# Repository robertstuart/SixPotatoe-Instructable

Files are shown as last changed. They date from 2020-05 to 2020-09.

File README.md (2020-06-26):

# SixPotatoe-Instructable
This repository contains all of the code and documentation needed to construct SixPotatoe, a high-performance inverted-pendulum robot.   A complete tutorial for building this robot can be found at: https://www.instructables.com/id/Build-a-High-Performance-Inverted-Pendulum-Robot/.

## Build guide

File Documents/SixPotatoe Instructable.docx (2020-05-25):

# Build a High-Performance Inverted Pendulum Robot

YouTube

(https://youtu.be/zkr5eXEhqio)

## Supplies:

Most of the parts are a available and some can probably be found locally. The only components that have only one source are the motors from Servo City and the motor controllers from Pololu.

- Printed Circuit Board (PCB). This must be ordered from a manufacturer. Step 1 explains how to do this. For people with the necessary skills, it is entirely possible to build SixPotatoe using a breadboard or prototyping board.
- Motor Controllers (https://www.pololu.com/product/2995) from Pololu. I use the 24v13 controllers but any of the single channel High Power controllers in this category should work.
- 5V Regulator (https://www.pololu.com/product/3782) from Pololu.
- Planetary gear motors (https://www.servocity.com/motors-actuators/gear-motors/heavy-duty-gear-motors) from ServoCity. SixPotatoe is pre-configured to handle five of these motors. These motors are described at the end of this section.
- Encoder cables. If you are using the Yellow Jacket motors, you will need these cables (https://www.servocity.com/encoder-breakout-cable-4-pos-jst-xh-mh-fc-to-4-x-1-pos-tjc8-mh-fc-300mm-length) (2). The HD motors already have the cables attached
- 6mm Clamping D hubs (https://www.servocity.com/0-770-clamping-d-hubs) (2) from ServoCity.
- 6-32, 1/2" screws (8) to attach the clamping hubs to the base plate.
- 12mm Hex Wheel Mount (https://www.servocity.com/12mm-hex-wheel-mount-hub-2-pack) (2) from ServoCity.
- 32mm Bore Bottom Tapped Clamping Mount (https://www.servocity.com/32mm-bore-clamping-mount)(4) from ServoCity.
- LIPO battery. I use a Turnigy 1200 mAh battery (https://hobbyking.com/en_us/turnigy-graphene-panther-1200mah-6s-75c-battery-pack-w-xt60.html). The battery should have XT60 connectors. Almost any six cell batteries will work. This battery will run for more than an hour before needing to be recharged. Larger batteries give more operating time but also give more weight at the top which helps climbing steep slopes and over rough ground. However, small batteries can give the same performance improvement if mounted high enough.
- XT60 connectors (https://www.amazon.com/LingSY-Female-Bullet-Connectors-Battery/dp/B06XV8L8L8). You will need one male connector to mount on the PCB. You will probably need a male and female connector to make a small battery cable if your battery does not have a long enough cable.
- 16 ga. black and red battery wire. Almost any stranded 14-18 ga. wire will work although I have a strong preference for silicon wire which is available from Hobby King (https://hobbyking.com/en_us/turnigy-high-quality-16awg-silicone-wire-1m-black.html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) or Amazon (https://www.amazon.com/Electrical-Gauge-Silicone-Cable-Black/dp/B0746HRVZP).
- Teensy 4.0 Arduino controller. These are available from a variety of sources including Sparkfun (https://www.sparkfun.com/products/15583)and PJRC (https://www.pjrc.com/store/teensy40_pins.html).
- Electrolytic capacitors for the motor controllers (2). I use 330uf from Pololu (https://www.pololu.com/product/882). Pololu recommend larger capacitors. A higher voltage would also be a good idea.
- 6 channel RC receiver and transmitter (https://www.amazon.com/DUMBORC-X6-Transmitter-Receiver-Protections-Controller/dp/B07Q112TQF). This is an inexpensive but very capable controller. This Instructable is designed around this controller although other controllers would probably work with a little modification.
- IMU (https://www.sparkfun.com/products/15335) from Sparkfun. This is an ICM-20948 mounted on a breakout with a Qwiic connector. The Qwiic connector can be used to add other sensors at a later point.
- HDPE sheets (https://www.amazon.com/Density-Polyethylene-Plastic-Sheet-Black/dp/B01JMAIYJW/). Other material can probably be used such as Phenolic sheets (https://www.amazon.com/Phenolic-Sheet-Standard-Tolerance-MIL-I-24768/dp/B0013HKZG8?th=1), alumunum or even baltic birch plywood. However, the frame needs to be very stiff, especially the base plate! I normally use 1/4" thick HDPE for all the plastic parts although I often use 3/8" for the bumpers. For the bumpers, HPDE is probably the only suitable material because of its extreme durability. I buy my HPDE from the scrap bin of a local plastics fabricator, but it is widely available from other sources.
- Threaded rod to hold the platforms. I use M5 rods from Amazon (https://www.amazon.com/uxcell-130mm-Stainless-Threaded-Silver/dp/B01M665GED?s=hi) but other sizes work just as well including 6mm, 10-32, 12-24, and 1/4". You will need four lengths that will normally end up with a length of 120 to 160mm. The ones listed from Amazon are 130mm which quite suitable.
- Wheels & Tires. I use Pro-Line F/R Masher 2.8" A/T Tires (https://www.prolineracing.com/tires/masher-2.8-all-terrain-tires-mounted-raid.asp), but many other tires will work just fine. The wheel must have 12mm hex mounts, which is standard for 1/10 scale vehicles. Also, the wheel should have a "wide offset". Any wheel that fits a 2wd Stampede®/Rustler® Front or 4x4 Stampede®/Rustler® Front and Rear should work. Even wheels with a narrow offset can be made to work by cutting away a bit of the base plate for tire clearance. The softer (more grippy) the rubber, the better. Also, the bigger the tire with more cushioning, the better. On the other hand, if you just plan on running on flat surfaces --- even grassy areas --- wheels like those from Bainbot (http://www.banebots.com/category/T81P_49.html) work nicely.
- LED momentary contact switch. The PCB is designed to use this switch from Sparkfun (https://www.sparkfun.com/products/10443). You may find it more convenient to mount a switch on the top plate. There are connection points on the PCB that makes it easy to hook up a cable to do this. For this, I like the LED switches from Adafruit (https://www.adafruit.com/product/1479).
- Hardware for mounting the PCBs. There are a number of ways to do this and all of them work just fine. You should choose hardware based on what currently have or what is available locally. Read the description in Step 8: Mounting the PCBs to understand the options.
- Mounting hardware for the PCBs. You should read the instructions in Step 8: Mounting the PCBs before deciding what parts to use.
- Male Header (https://www.sparkfun.com/products/116)
- Female headers (https://www.sparkfun.com/products/115) (2).
- Schottky Diode (https://www.sparkfun.com/products/10926) (2).
- Ceramic Capacitor 0.1uF (https://www.sparkfun.com/products/8375)
- Electrolytic Capacitor 100uF (https://www.sparkfun.com/products/96)
- Qwiic cable (https://www.sparkfun.com/products/14426).
- Seven resistors: One each of 150 ohm, 470k ohm and 68k ohm and four 1k ohm resistors.

If you can't find some of the miscellaneous electronic components locally or in your parts bin, they can be purchased from either Digikey.com or Mouser.com. Many of the small mechanical parts can be purchased at your local hardware store. If they don't have exactly the part specified, you can usually find something similar there that will work just fine.

The total price for these components should be $400 - $500.

Before starting this project, you will probably want download and print out the mechanical drawings in the repository. These can be found in https://github.com/robertstuart/SixPotatoe-Instructable, in the “Mechanical Drawings” directory.

## Tools

- Table or band saw to cut the platforms.
- Drill. A drill press is nice but not absolutely necessary.
- Saw to cut the bumpers. The bumpers could be omitted but this is not recommended. A jig saw, coping saw or even a router could be used to fashion the bumpers. I expect that those with good 3D printer skills could make something that would work quite well.
- Soldering iron. A temperature controlled iron is recommended.
- A modest assortment of screwdrivers, wrenches, and pliers

## Choosing a motor

The robot can use any of the following motors, available from Servo City. I have tried all of these motors and I have a slight preference for the HD 612 RPM but there are reasons, including availability, that you might want to choose another one. Here is the complete list:

Yellow Jacket 435 RPM - This motor is a little cheaper, is a little less powerful that the equivalent HD motor listed next. The encoders don't have as much precision. Still, the differences would be hard to detect in most situations. Its top safe speed is around 15 KPH (9 MPH).

HD 437 RPM - For all practical purposes, this motor is equivalent to the Yellow Jacket 435 motor described above. It does have a teeny bit more power and better encoder precision, so in rare instances it will perform a little better. In fact, SixPotatoe used this motor in all of the skate park “dimple” scenes in the YouTube videos.

HD 612 RPM - This is the ideal motor for many people. In fact, I delayed the publication of this Instructable until this motor became available again. Its top speed is around 21 KPH (14 MPH) and it manages jumps and rough ground with ease and is plenty fast. It is very stable and runs a long time on one battery charge.

Yellow Jacket 1150 RPM - This motor is just like the Yellow Jacket 435 RPM motor but is almost three times as fast. It won't stay upright quite as well over rough ground and jumps, but the speed is very impressive. It is a lot of fun to drive. Its top safe speed is around 40 KPH (25 MPH). In my opinion, this is really faster than you will normally want to go. It can do considerable damage to itself, other things and people when it hits something at that speed. It will appear to be slightly unstable and out-of-control at its top speeds since it will bounce a little bit when encountering slight undulations in the surface. It consumes considerable battery power; especially over rough terrain and the motors will get slightly warm. SixPotatoe was using this motor for most of the high-speed scenes in the YouTube video.

HD 1621 RPM - If you are addicted to speed and your personal and property insurance payments are up to date, this is the motor for you. Its top speed is about 55 kph (36 mph). In the skate park, I have made some really spectacular jumps using this motor. (I have been unsuccessful in making it land properly in many cases, so there is often damage. As a result, I have abandoned any further attempts.) Its operation over rough ground is not up to that of the lower RPM motors, but it is still very impressive. The safety, battery power and motor temperature caveats of the previous motor apply even more to this motor. Also, I have not done as much testing with this motor so it may not be as well tuned as it could be.

## Step 1: Create the PCB

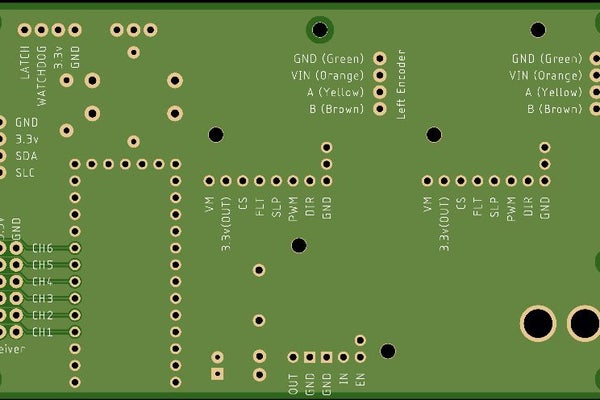
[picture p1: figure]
Create the PCB
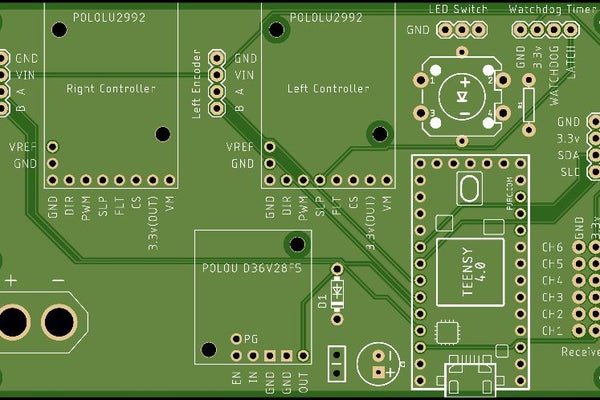
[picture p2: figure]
Create the PCB

The Gerber file for manufacturing the PCB is included in the Eagle Files directory of the GitHub Repository (https://github.com/robertstuart/SixPotatoe-Instructable). There are a variety of PCB manufacturers but we have been very happy with the price, quality, and delivery times of JLCPCB (https://jlcpcb.com/). Whatever manufacturer you use, follow the directions from the manufacturer for uploading the Gerber file and ordering your board(s).

Note that it is possible to make this robot using prototyping boards or even breadboards. In fact, early versions of this robot were made using both of these methods. The schematic should give you all of the information you need. The wiring diagram, Wiring.pdf, also available from the GitHub Repository, should also help but be aware that it is doesn't exactly reflect the schematic. Use the schematic and just use the wiring diagram as a general guide!

## Step 2: Top and Bottom Plates

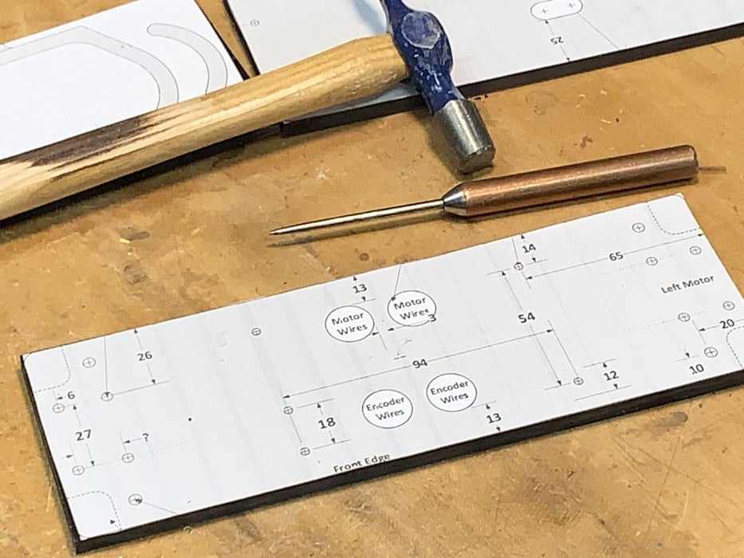
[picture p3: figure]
Top and Bottom Plates
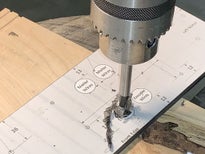
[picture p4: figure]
Top and Bottom Plates
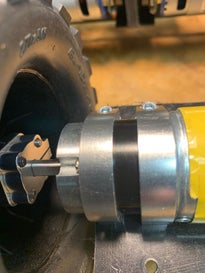
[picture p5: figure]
Top and Bottom Plates
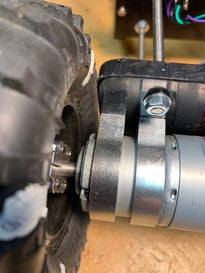
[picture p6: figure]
Top and Bottom Plates

Cut the two HDPE plates to the dimensions shown in the mechanical drawing. Ideally, this can be done on a table saw but a band saw works also. It is a good idea to round the four corners an all the edges. This can be done with a sander. A wood plane also works quite well. The edges can also be carved smooth with a regular knife or an Exacto knife.

To drill the holes it is usually easiest to make a template by printing out the mechanical drawing. Be sure to print them out using a scale of 100%! Then tape or glue the drawing to the platform. Gluing with rubber cement usually works best. You can then punch the center of each hole with an awl or center punch to give a solid target for the drill so that the bit doesn't wander. The holes can be done with a hand drill although a drill press is a little easier. I find that a forstner bit works best for the larger holes.

Only the motor mounts require any accuracy. To get the spacing between the two motor mounts, install the clamps on your motors and measure the spacing. Normally, you will want to have the gear box protrude a bit from the outside motor mount. I usually adjust the position so that the heads of the screws holding the gearbox end cap are just outside the clamp. The picture shows this relationship.

On the top plate, do not drill the holes for the bumpers. These can be more accurately drilled when the bumpers are completed in the next step.

## Step 3: Bumpers

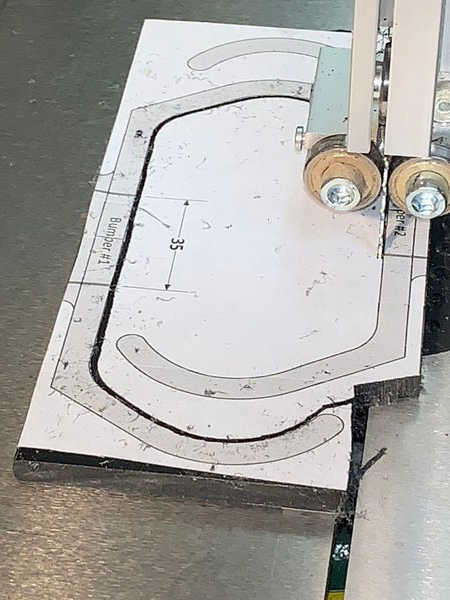
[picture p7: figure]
Bumpers
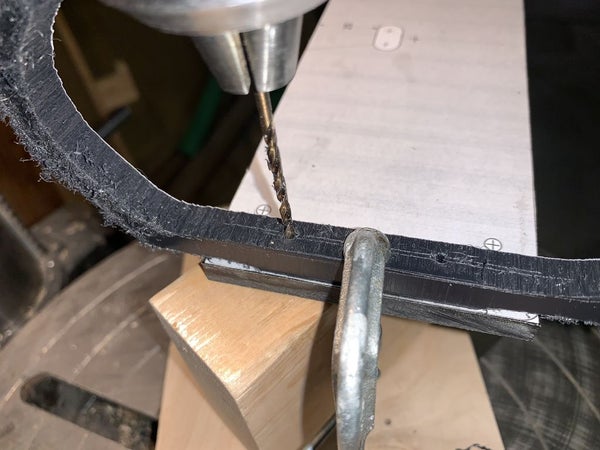
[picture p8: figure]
Bumpers

Again, the easiest way to create the bumpers is to use the printed diagram as a template. There are two base lines that indicate the bottoms of the bumpers where they will be attached to the top plate. Measure the distance between these two lines. Cut out a plate off HDPE so that it has exactly this width. Cut out the printout along these base lines and then glue the template to the plastic, aligning the baselines with the edges. The bumpers can be cut out on a band saw. A simple coping saw also works quite well. After cutting, the edges can be smoothed by carving with a knife or sanding using a medium grade sandpaper.

1/4" HDPE works well for the bumpers but I have a slight preference for 3/8" HDPE since it is a little stronger. The bumpers are the most likely part to get damaged in a driving accident, so you might consider making a couple more at this point. If you are a careful driver, you can just make the required two.

Once the bumpers are cut, you should drill the two mounting holes. This is something you should do very carefully. The bumpers are most likely to break at these mounting holes. They will be strongest if you drill exactly in the center. This hole should be quite small. I normally use M2.5 or 4/40 screws. The holes for the screws should be slightly smaller than the screw. This way you will be able to drive the screw through the hole with a hammer so that the sides of the plastic will bulge out slightly.

After you drill the holes but before you drive in the screws, you should clamp the bumpers to the top plate in their correct position. Using the same drill bit, you can use the bumpers as a drill guide to drill through the top plate. When you un-clamp the pieces, you can then re-drill the hole through the plate so that it has better clearance. When you finally mount the clamp on the top plate, it is a good idea to put a washer underneath the head of the screw. Also, since it is normal to carry SixPotatoe using these bumpers as a handle, it is a good idea to grind off any part of the screw that protrudes from the nut it so that it is comfortable to carry in this manner.

## Step 4: Encoder Shields

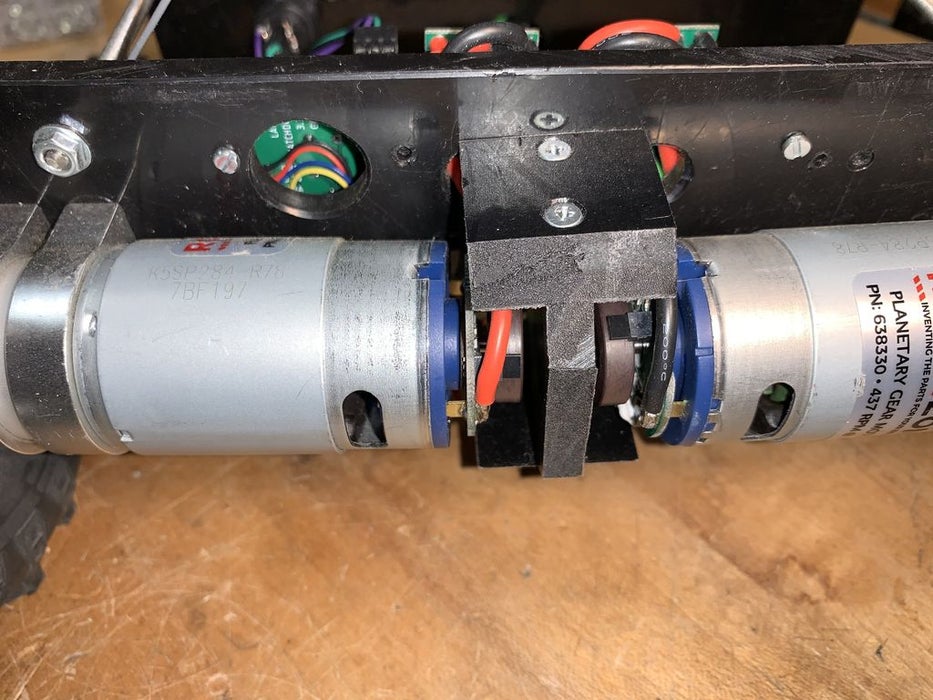
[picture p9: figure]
Encoder Shields

The encoder shields protect the encoders from damage, which can easily happen over rocky ground. They also add stiffness to the entire base plate.

First of all, you have to decide what kind of screws to use to hold these pieces together. Smallish flat head self tapping (sheet metal) screws work best. M3, 20mm are about the right size. In the USA, #4 or #f6 sheet metal screws of about 3/4" in length work well. You may want to use the same size and type of screw in the battery tower in the next step.

Cut out the two sides as shown in mechanical drawing. The shape is not important. Place one of the sides in its proper position and, using an awl, mark the position of the holes on the center piece. This gives the vertical position of the screw. Hold the center piece in a vice or clamp and carefully mark the position of the screw hole in the center of the piece using the previously marked position to get the height. Then drill a guide hole the depth of the screw. Countersink the hole for the flathead screws. Attach the 3 pieces with the screws.

Find the proper placement for the shield. This should be in the exact center, both vertically and horizontally. You may want to temporarily mount the motors to make sure that the position is correct. Mark the position of the shield on the bottom of the bottom plate. Masking tape is probably the best way to do this since no pen or pencil can mark on this plastic. Alternatively, an awl can be used to scratch the outline. You then need to drill four holes in the assembly to accommodate the self taping screws. The size of the drill should be about the size of the shaft of the self taping screw so that the screws get a good grip. Once the hole are drilled in the shield, you can then punch centering holes in the base plate to match the shield assembly. Then drill the matching holes through the base plate with a drill bit that creates clearance for the self taping screws. Once that is done, you can mount the shield with the screws.

This technique for mounting the shield will also be used in the next stop to create the battery tower.

## Step 5: Battery Tower

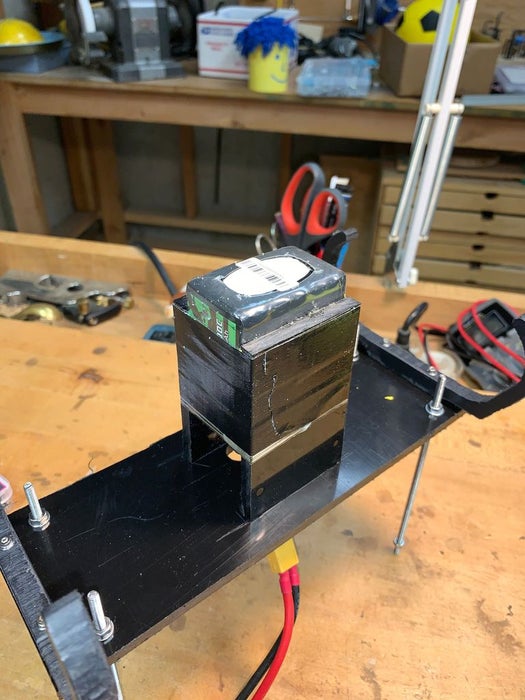
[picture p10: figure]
Battery Tower
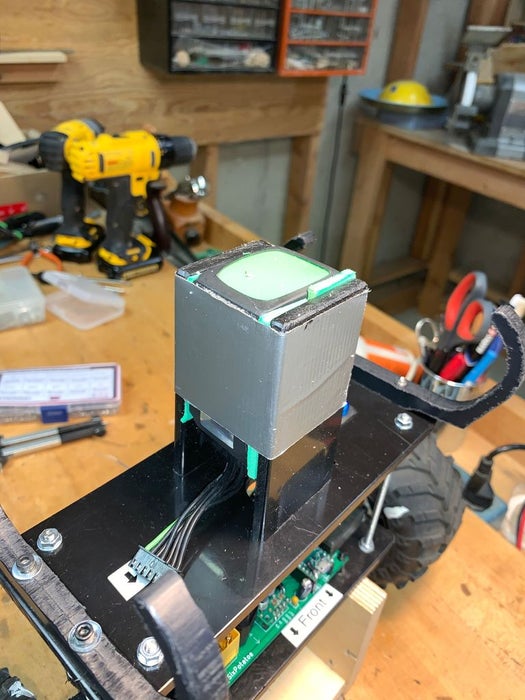
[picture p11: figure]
Battery Tower

The battery tower is not absolutely required. In fact, all batteries, especially larger batteries, can just be strapped to the top plate so that the battery tower is not needed at all. The battery tower, described here, helps a little bit with performance on steep slopes and rough ground, so it is the preferred method. If you decide to mount the battery flat on the top plate, you might consider lengthening the threaded rods to regain this lost performance. Another consideration is that the battery tower makes it easier to mount a head on the robot.

The battery tower must be custom fit to battery that you have. If the power wires on the battery are long enough, you may be able to plug directly into the PCB. For many batteries, however, you will have to manufacture a short extension so that the battery can be mounted at the proper height. For the specified battery, a height of around 90 mm seems about right. The width should be as wide as the battery.

Once the size is determined and the pieces are cut out, you may have to create some spacers to go between the battery and spacers. You can see this in one of the pictures above. This is because batteries are often a little wider at the end with the connectors. The spacers prevent any pressure on the connector wiring. Almost any material will work for spacers. Often cardboard is the easiest option.

Sandwich the tower pieces, spacers and battery together placing glue between each of the pieces. Rubber cement or contact cement works best in this situation. Double-sided sticky tape works well also. Lightly clamp the entire sandwich together and set it upright and adjust everything so that the bottoms rest flat on a horizontal surface and the sides are vertical. Allow the glue to dry. After the glue is reasonably dry, remove the clamps and tape the whole thing together. I like duct tape or electrical tape but almost any tape will work.

You must decide what kind of screw you are going to use to attach the tower to the top plate. M3 or M4 self taping screws of 20-30mm work well. In the US, #6 sheet metal screws of about 1" seem about right.

Take the battery tower and position it on the top plate so that it is properly centered. Mark the position of the battery tower supports on the top plate using masking tape. Turn the battery tower upside down and mark the position of the guide holes with an awl. These should be exactly centered on the supports and about 8mm from the end. As with the encoder shields, you need to drill tap holes into the tower sides and, after marking the position on the top plate, drill clearance holes in the top plate.

If you decide to mount and LED switch on the top plate, this is the time to do that.

Mount the battery tower guiding the power cable through the top plate.

Step 6: Mount the Motors

The motors should be bolted to the base plate using the .. There are slightly different directions for the HD and Yellow Jacket motors.

Yellow Jacket Motors:

Remove and throw away the plastic shields for the encoders. Wires from the motors need to be kept away from the encoder wires so that spikes from the motor do not interfere with the encoder signals. This interference can cause serious problems in the operation of the robot, particularly during aggressive maneuvers. Completely pull apart the red and black part of the wire pair. Mount the motors so that

HD Motors:

You should clip off the connector at the end of the six-wire cable. Then you should remove the red and black wires by clipping them off right at the encoder PCB. Cut two lengths of the red 16 Ga. stranded wire to about 130mm. Do the same for two pieces of the black wire. Strip off enough insulation from one end of each of the wires so that it can be soldered to the motor. Sold a red wire to the +M connection and a black wire to the -M connection. Be sure to solder them so that they are leading away from the encoder wires.

## Step 7: Prepare the Teensy

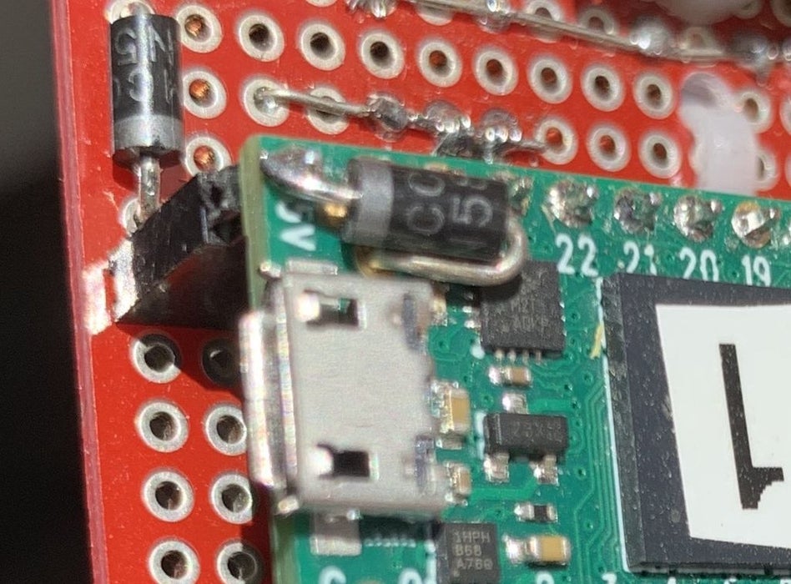
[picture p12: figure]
Prepare the Teensy

The Teensy 4.0 must be modified so that it can be powered by either the USB or the battery. A trace is cut on the back side of the board and a Schottky diode is added to the front side. The trace is shown on the "Teensy 4.0 Back Side" drawing here: https://www.pjrc.com/store/teensy40.html. On the diagram you can see a connection point labeled VUSB, This is the point where the anode side (without the stripe) of the diode must be connected on the top side. After cutting the trace on the back side, place the diode and solder it on the top side so that it connects the VUSB to the 5V (Vin) point as shown in the picture above.

If you have purchased your Teensy without headers, you must solder 14-pin male headers to the bottom side of the board.

## Step 8: Wire the Battery Connector on the PCB

By now, your PCBs should have arrived from China.

We will hook up the power connector first since that is easiest and safest to do when there are no other connectors of components on the board. It is best to have one or two people help you with this step since the PCB, the connector, and the wire all need to be held in place when soldering. First of all, cut two pieces of black and two pieces of red 16 guage wire to a length of about ??cm. Strip about 5mm of insulation from one end of each wire. I also like to insert a female connector (not from a battery!) into the male connector to make it easier to hold on to the connector.

Start heating your soldering iron. A good hot iron is needed. I set the temperature to about 400 degrees Celsius.

Now comes the hard part. I like to clamp the connector in a vice and then place the board onto the clamped connector. This is where you will need someone to hold the board onto the connector. This helper should use something like a screw driver or an awl to hold the board firmly onto the connector. Then place the two stripped ends of black wires into the negative terminal. and press the wires against the PCB while directing the wires toward where they will eventually connect to the motor controllers. Either have someone else hold the wires against the PCB or use something like a clothes pin to hold the wires.

Stop! Recheck to make sure that: 1) you are mounting the connector on the correct side of the board, 2) the connector + and - are oriented in the correct direction and 3) the black wires are connected to the minus side of connector terminal.

Now you can solder the wires. It will take some time to heat this all up, but once it is hot enough, the solder should flow easily. Apply just enough solder to just fill the connector. Be sure that the solder flows between the connector and the plated through hole on the PCB.

Solder the two red wires in the same manner.

Cut the headers so that you have two 14-pin strips to mount the Teensy and three 6-pin strips to mount the radio receiver. You should cut the strips at a pin, destroying that pin, so that you have the desired number of pins remaining. For the Teensy headers, the ends can be left rough if you want but the three 6-pin strips must be filed off so that they fit into the radio receiver housing. You can do this with a piece of medium sandpaper on a flat surface or with a file. Finger nail files work quite well for this. If you want to put a connector to an LED switch on the top plate, you can also create a 3-pin header for this.

Solder all of the headers to the PCB. This is another situation where it is helpful to have another person hold everything together while doing the soldering.

Solder the resistors, capacitors, and diode to the PCB. The resistors...

## Step 9: Mounting the PCBs

Before you mount the motor controllers, you should add the large electrolytic capacitors to them in the space provided. Be sure to get the polarity correct.

There are four circuit boards that are mounted directly on the main PCB: the two motor control boards, the 5V regulator and the IMU. The usual way to mount these is to use a standoff or spacer to hold the board away from the main PCB and then clamp the sandwich together using a screw and nut. A 6mm or 1/4" spacer works quite well. An M2 or 2-56 screw and nut holds them together. There are probably many other ways to do this. I find that the parts from this kit from Amazon (https://www.amazon.com/HVAZI-240pcs-Standoffs-Assortment-Male-Female/dp/B07JYSFMRY) contains almost everything you need except for the small screws. The IMU, mounted on the bottom, has larger mounting holes so you can use the M2.5 standoffs. In any case, a trip to the hardware store will usually yield a solution.

Once you have mounted all four boards, you need to use the same general technique to mount the main PCB to the bottom plate. I find that 10-15mm or 1/2" spacers are about right. The spacers should be long enough that IMU does not touch the base plate. The screws and nuts can be M2.5 or 4-40. Again, the spacer/standoff kit from Amazon has parts that work very well in this situation.

Mount all of the boards into their proper position. Note that the IMU is mounted with the connectors near the main PCB and oriented so that the label "ICM-20948" is nearest the Teensy.

Once the boards are mounted, the connections/jumpers can be installed. To do this, run a small solid wire between the board and the main PCB and the solder each end and clip off the ends. For the motor controllers, only the GND, DIR, and PWM need to be connected. For the regulator, only the IN, GND, GND, and OUT need to be connected.

The easiest way to connect the IMU is to hook up a QWIIC connector to the board and solder the wires from the connector to the GND, 3.3V. SDA, and SCL on the main PCB. If you have purchased a connector cable, you can snip off one of the connectors. The black wire will be GND, the red wire 3.3V, the blue wire SDA and the yellow will be SCL. You can also create your own connections using the plated through holes on the side of the IMU board. Note that the QWIIC connectors provide a convenient way to expand the capabilities of SixPotatoe without additional wiring.

The last step is to connect the wires from the battery connector to the motor controllers. Train the red and black wires to the GND and VIN connections on the controllers. Cut the wires to the proper length. Before stripping the wires, it is usually easiest if you tin the ends so that the wire doesn't fray when you strip the wire. After you strip the wire, place the red wire into the VIN and the black into the GND and solder them. It will take a fairly hot iron to do this but be careful; the board should not become so hot that other components on the board become unsoldered, thereby ruining the board. Pololu provides screw terminals that can be mounted on the boards. If you wish, you can use these rather than solder the wires.

## Step 10: Set Up the Arduino Development Environment

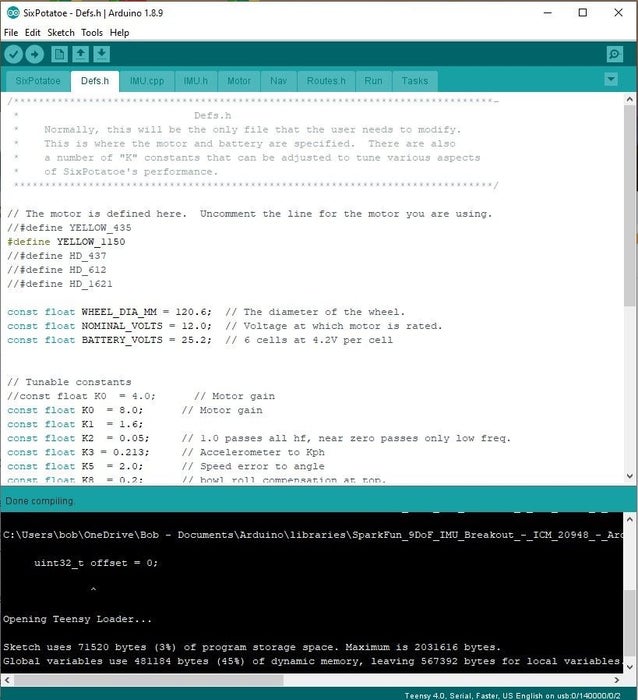
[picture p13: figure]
Set Up the Arduino Development Environment

If you have not used the Arduino development environment before, you need to spend a little time setting it up and learning how to use it. There are many tutorials (and Instructables!) that will get you going.

First of all, get the current SixPotatoe code from the GitHub repository, https://github.com/robertstuart/SixPotatoe-Instructable, and install it on your system. Again, if you have not used GitHub, there are tutorials and Instructables that explain how to do this. I think the easiest way is to click the "Clone or download" button and then download the zip file and put the code wherever you do your development.

You must then set up the Teensyduino environment. Go to this web page, https://www.pjrc.com/teensy/td_download.html, and follow the directions for your environment. Once everything is set up, you will have to start up the Arduino development environment, click on the "Tools" menu and select "Teensy4.0" from the "Board:" menu. Once you are this far, it is a good idea to hook up your Teensy to determine that the SixPotatoe compiles correctly.

## Step 11: System Testing

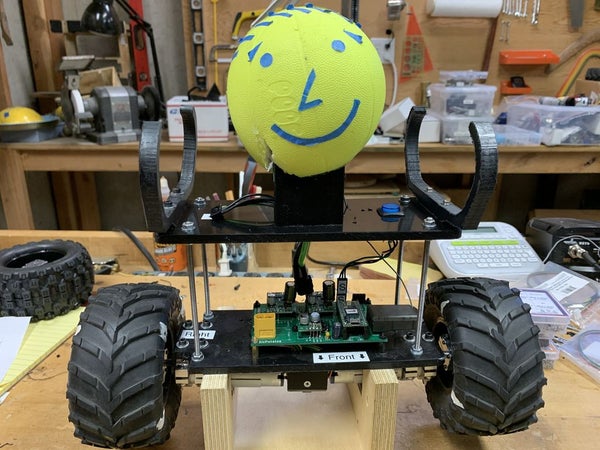
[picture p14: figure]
System Testing
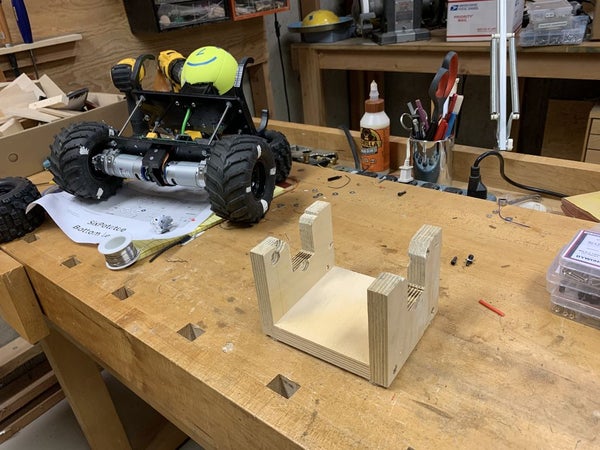
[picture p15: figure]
System Testing

Before you start testing and running SixPotate it is useful to have some sort of test stand. Something like four soda cans will work just fine but I like to make a simple stand out of wood. You can see the cradle that I use in the above pictures. Keeping SixPotatoe in the stand, also keeps the tires from developing "flat spots" when sitting around idle.

After all of the connections have been made, it is a good idea to make some simple checks to be sure that there are no major wiring errors. If you have an ohm meter, measure the resistance between the two battery terminals on the PCB. This should measure in the meg-ohms. You should do the same between the Gnd and Vin on the Teensy. These are the two end pins near the USB connector. This should also be in the meg -ohms.

Next, you must set values in your SixPotatoe.ino file to match the motors that you have installed. There are parameters for several motors already established in the file:

RZONE_1621
RZONE_612
RZONE_437
YELLOW_1140
YELLOW_435

One of these values must be specified in first #define in the beginning of the defs.ino file. The line defining your motor should be uncommented. This will establish appropriate values for each of these motors. If you have other motors, you can probably come up with reasonable values for your motors using the previous definitions as a guide.

There are four system tests:

System Test #1

This test checks that the IMU is working. Near the bottom of the defs.h file there are some lines that activate the system tests. You will need to set the appropriate system test to "true". For this test, you will need to set the lines as follows:

// Test defines

const bool IS_TEST1 = true; // Set to be true for the 1st system test.

const bool IS_TEST2 = false; // Set to be true for the 2nd system test.

const bool IS_TEST3 = false; // Set to be true for the 3nd system test.

const bool IS_TEST4 = false; // Set to be true for the 4th system test.

Hook up the USB connector on the Teensy to your computer that is running the Arduino development environment. The light in the RC receive should come on. Upload the SixPotatoe sketch and run the serial monitor. The LED on the Teensy should blink and the output on the serial monitor should show the pitch, roll, and yaw, in degrees, of SixPotatoe. Move SixPotatoe around and see if the orientation looks correct. All three values should be near zero when SixPotatoe is upright. The pitch should go positive as SixPotatoe is leaned back and negative as SixPotatoe is leaned forward. Roll will go positive as the left motor is lifted up and Yaw will go positive as SixPotatoe is rotated clockwise.

System Test #2

This test checks that the Radio Control works. If you haven't already done it, this is the time to bind the transmitter and receiver. Follow the instructions that came with the RC unit to do the binding.

Once the binding is complete set IS_TEST1 to false, and IS_TEST2 to true. Upload the program and look at the serial monitor output. Channel 1 value should vary as you turn the steering control, and channel 2 should vary as you manipulate the trigger (throttle). The top left control should change channel 5 and the top right control should change channel 6. Channel 3 is toggled by the push button on the side of the handle and Channel 4 has a 0, 1, and 2 state controlled by the slide switch.

System Test #3

This test checks the operation of the motor controllers and motor encoders. Also, SixPotatoe should be sitting up on a test stand of some sort. Plug the battery into the connector on the PCB. Unplug the USB from the computer. The LED on the Teensy should continue to blink. Plug the USB connector back in. Set IS_TEST3 to true and all of the other tests to false. Upload the new SixPotatoe program.

Press the LED push-button. The LED should come on. Toggle the on/off button on the controller. The LED on the switch should turn on and off just like the LED on the controller. Turn the LEDs on. Pull the trigger. Both motors should be operated both forward and backwards by the trigger. The motors should go forward when the trigger is pulled in and backwards with the trigger is pushed out.

The first two columns displayed in the serial output show the right and left wheel speed. The wheel speed should be positive when the trigger is pulled and negative when it is pushed out. The direction will vary depending on the motor encoders and gear box. If the direction is incorrect, this can be easily fixed by simply changing the pin definitions in SixPotatoe.ino.

Configuration A:

const int ENC_B_LEFT_PIN = 20;

const int ENC_A_LEFT_PIN = 21;

>const int ENC_B_RIGHT_PIN = 22;

const int ENC_A_RIGHT_PIN = 23;

Configuration B:

const int ENC_B_LEFT_PIN = 21;

const int ENC_A_LEFT_PIN = 20;

const int ENC_B_RIGHT_PIN = 23;

const int ENC_A_RIGHT_PIN = 22;

Use whichever configuration works for the motors you have.

The wheels will turn in opposite directions when the steering control is is manipulated.

This is probably the appropriate place to do the initial setup for the adjusting knobs that are underneath the lid on the controller. The bottom left knob adjusts the gain for the steering. This should probably be turned all the way up to 100. The knob above that sets the centering for the steering. This should be set at the center, 0. The right bottom knob sets the gain on the throttle. If you want to run the robot at maximum speed you must set this at 100. However, I recommend that this be set at 50 or lower while you are learning to operate the robot. Also, it is useful to set this at a low value for new users, particularly young children. The knob above that should be set to the center position.. It can be used to set the robot to zero speed. It can be quite useful to stand still on sloping ground.

Both of the switches at the top should be set to the left.

System Test #4

This test checks the internal control circuitry and software for motor speed control. As before, set IS_TEST4 to be true and all other tests to false. The motors can be turned on and off, either by pressing the button on SixPotatoe or CH3 on the controller. Again the measured speed will appear in the serial output. If SixPotatoe passes this test, it should work correctly in normal operation.

Preliminary balancing test

Set all the tests to false so that the system is in its normal running mode. Plug in the battery connector and the LED on the Teensy should show its heartbeat. While holding SixPotatoe nearly vertical, press the on/off button once and the LED on the button should come on. Press it again after a second or so, and the light should go off. The motor may have started up while the light was on. If you repeat this while tipping SixPotatoe forward or backwards a few degrees you will see that the motors will start accelerating more forward the more SixPotatoe is leaning forward. You will see the opposite effect as you tip SixPotatoe backwards. If this is what you see, your robot is ready to run!

## Step 12: Running SixPotatoe

I think that you will find that SixPotatoe is a lot of fun to drive. If you are not used to the RC controller, it takes a little time to get used to the steering and accelerator – particularly if you are using one of the high RPM motors. Here is some general information to help you get going:

Mounting the wheels

Mount the ”D” clamp on the end of the motor shaft. Make sure that the shaft does not protrude past the face of the clamp. Tighten the clamp. Then mount each of the 12mm wheel adapters to the clamp and tighten the four 6-32 screws.

Next, the wheels must be mounted on the wheel adapters. Be careful that the 8-32 wheel-mounting screw does not bottom out on the motor shaft. In the worst case, you can tell that the screw is bottomed out when the wheel is loose after tightening the screw. If the wheel feels solid, it is still sometimes safest to add another washer under the 8-32 screw to be sure that everything is tight.

The LEDs

When you connect the battery, the LED on the Teensy will start blinking at about two times a second. This tells you that it is going through its usual 200 per second cycle. If the light is not blinking, something is very wrong and SixPotatoe will not work.

The system LED on the switch should initially be off. If you hold SixPotatoe in the vertical position and press the switch, the light should come on and SixPotatoe will start balancing. If you press the switch while SixPotatoe is lying down, the LED will flash rapidly indicating that it is ready to go. In fact, you can just start lifting up SixPotatoe and it will continue to get up by itself. With a little manipulation of the throttle, it will easily get up as described below.

The controller

You may have set up the adjustments in the controller but we will do it again here to verify that everything is working. Be sure that the CH4 three-position switch is pulled all the way back. Flip up the lid to the four adjustment knobs. The top left switch should be set to the left, "Nor", position. The top right switch should also be set to the left, "NOR", position. The top left knob should be set to point straight up to the "0" position. This sets the steering bias and there is little need for it with SixPotatoe. The bottom left sets the steering gain. This is normally set at its maximum, 100. Sometimes it is useful to set this at a lower value, particularly for new users or young children who often turn the steering knob too much. A lower value on this adjustment makes the steering less sensitive. The top right adjustment should be centered at the "0" position. This can be adjusted to make SixPotatoe not wander off forward or backward. This can be particularly helpful in making it stand still while on a slope. The bottom right adjustment is the throttle gain. Again, it is useful to turn this back when learning the system and for young children.

There is a RC-Control.pdf file on the repository that has templates for the top of the RC controller that you can cut out and glue to the controller that should help you with these settings.

The CH3 button on the controller turns SixPotatoe on and off and duplicates the function of the switch on SixPotatoe. You should realize that the controller only transmits commands to SixPotatoe and receives no information from SixPotatoe. Therefore, the CH3 button and the button on SixPotatoe may be out of sync if you press the switch on SixPotatoe.

Other than that, control of SixPotatoe is very simple: pulling on the trigger causes SixPotatoe to go forward and pushing on the trigger causes SixPotatoe to go backwards. Similarly, turning the steering knob clockwise causes him to turn right and counter-clockwise causes him to go left.

Generally speaking, operation of the throttle will not affect the steering and vice versa. However, SixPotatoe does try to prevent turning a corner so sharply that it tips over. Therefore, very sharp turns will not be possible at high speeds.

Getting Up

SixPotatoe can get up from lying on the ground and it seems to delight everyone who sees it. There is no special code to make this happen; it is just the result of his general ability to stay upright. If SixPotatoe is lying down, you can drive around while lying down. Sometimes this is necessary to get into some open space. SixPotatoe gets up most easily when it is traveling, motors first, and the throttle is rapidly reversed. Usually, just a flick of the throttle will bring him upright. Also, he can be brought upright with a just a little kick from the toe or by "falling" off of a short drop, such as a curb. Getting up requires good traction, so these maneuvers may not be successful on slippery floor, wet grass, loose gravel, etc.

Steps and Curbs

SixPotatoe tries to stay upright when encountering vertical drops. It does pretty well at this but it is not perfect. Yet! When encountering a vertical drop, it is a good idea to have SixPotatoe going at a steady speed and be in a relatively vertical position. Drops are less likely to be successful if SixPotatoe is rapidly accelerating or decelerating.

Also, large drops are potentially harmful. SixPotatoe has no suspension so the small wheels must absorb all of the impact of a large drop. I haven't bent any axles or ruined gear box bearing yet but I expect there is considerable risk of both with larger drops. Jumping off of a chair is about as large a drop as I would attempt and, even then, I am reluctant to do it. I have successfully jumped off of a tabletop but this always seems a little risky.

Rough Ground

Traveling over rough ground such as deep grass or rocky areas is one of SixPotatoe’s most striking abilities. It is one thing that people are always surprised to see. There are two major factors that limit this: weight distribution and wheel size. SixPotatoe could be built to be taller with bigger wheels but that would involve other compromises. It is kind of fun to see if you can push SixPotatoe through difficult terrain and I urge to try different kinds or terrain to see how he copes. He has never been near the ocean! If you take him to the beach sometime, please send me a video!

Autonomous Navigation

SixPotatoe can navigate a course with surprising accuracy. You can see this in the videos of TwoPotatoe and ThreePotatoe navigating through AVC contest sponsored by Sparkfun. SixPotatoe has much of the same navigation code embedded in it so it is theoretically capable of the same thing. Instructions on how to do this are posted on the TwoPotatoe web site (http://twopotatoe.net/).

## Step 13: Final Caveats

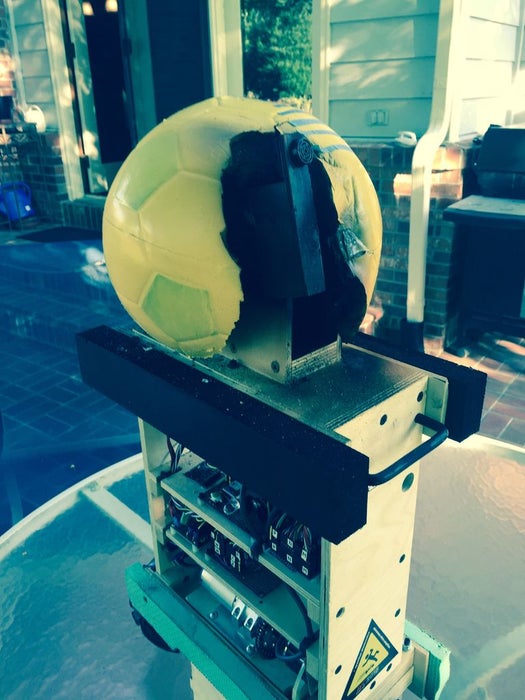
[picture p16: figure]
Final Caveats
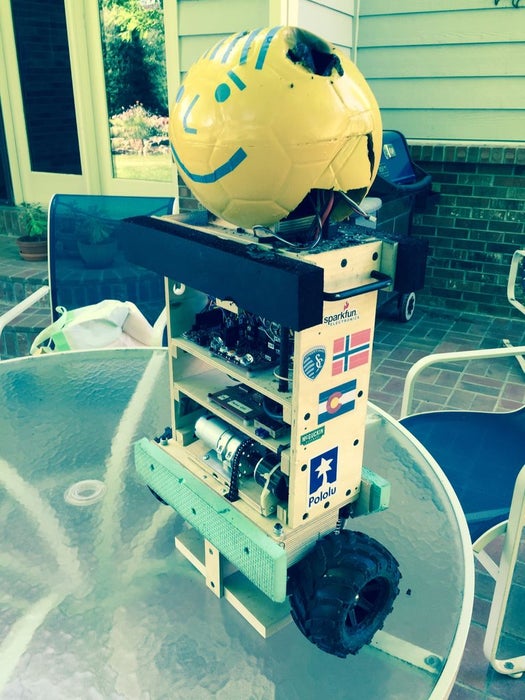
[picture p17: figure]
Final Caveats

Skate Parks

Skate parks are an ideal place to exercise SixPotatoe's many capabilities. There are a few words of caution, however. The first is general safety considerations. Skate parks are sometimes full of young children. At other times, there are fairly young adults moving very fast and doing very athletic tricks. You should exercise caution at all times while at the skate park. Skate parks are usually relatively free early in the morning and during the school year. SixPotatoe tends to draw a crowd wherever he appears so it is usually best to use the slate park while school is in session or early in the morning.

Also, one of the skate park that I use in Lafayette, Colorado has a sign stating that motorized vehicles are prohibited. A literal interpretation of this suggests that robots like TwoPotatoe are not allowed. No one has ever said anything to me although I did have a police car pull up and the officer got out of the car with a video camera. I turned out that he thought the robot was really cool and wanted to film it to show to his children.

Lipo batteries

Lithium polymer batteries are a known hazard. There are many articles on the internet explaining their proper care. As an example of what can happen, I once accidentally punctured the battery in TwoPotatoe. I managed to get TwoPotatoe outside before any serious damage occurred but the house filled up with smoke and set the fire alarms off. Be careful!

Also, follow the usual guidelines of Lipo batteries. They should be maintained at the appropriate charge and shouldn't be deep discharged.

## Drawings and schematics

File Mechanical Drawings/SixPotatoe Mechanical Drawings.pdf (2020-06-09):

235

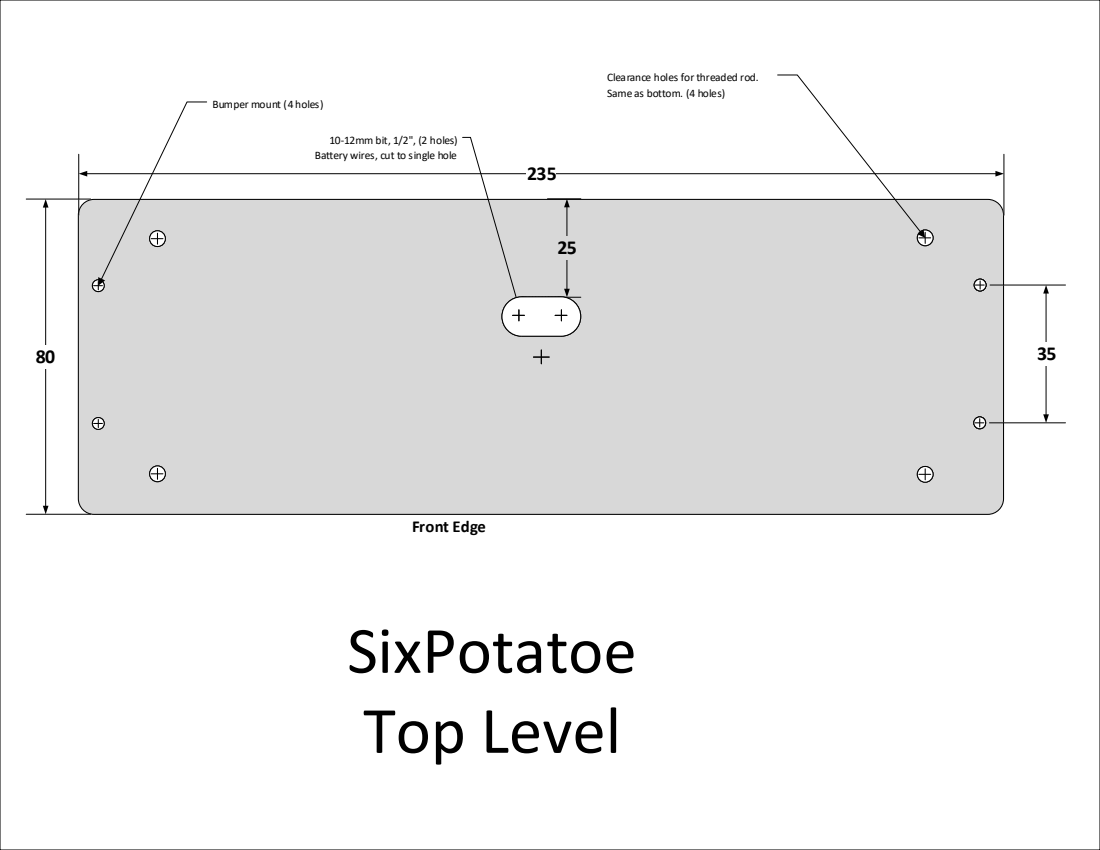
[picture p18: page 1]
SixPotatoe Top Level; Front Edge

Clearance holes for threaded rod.
Same as bottom. (4 holes)

Bumper mount (4 holes)

10-12mm bit, 1/2", (2 holes)
Battery wires, cut to single hole

235

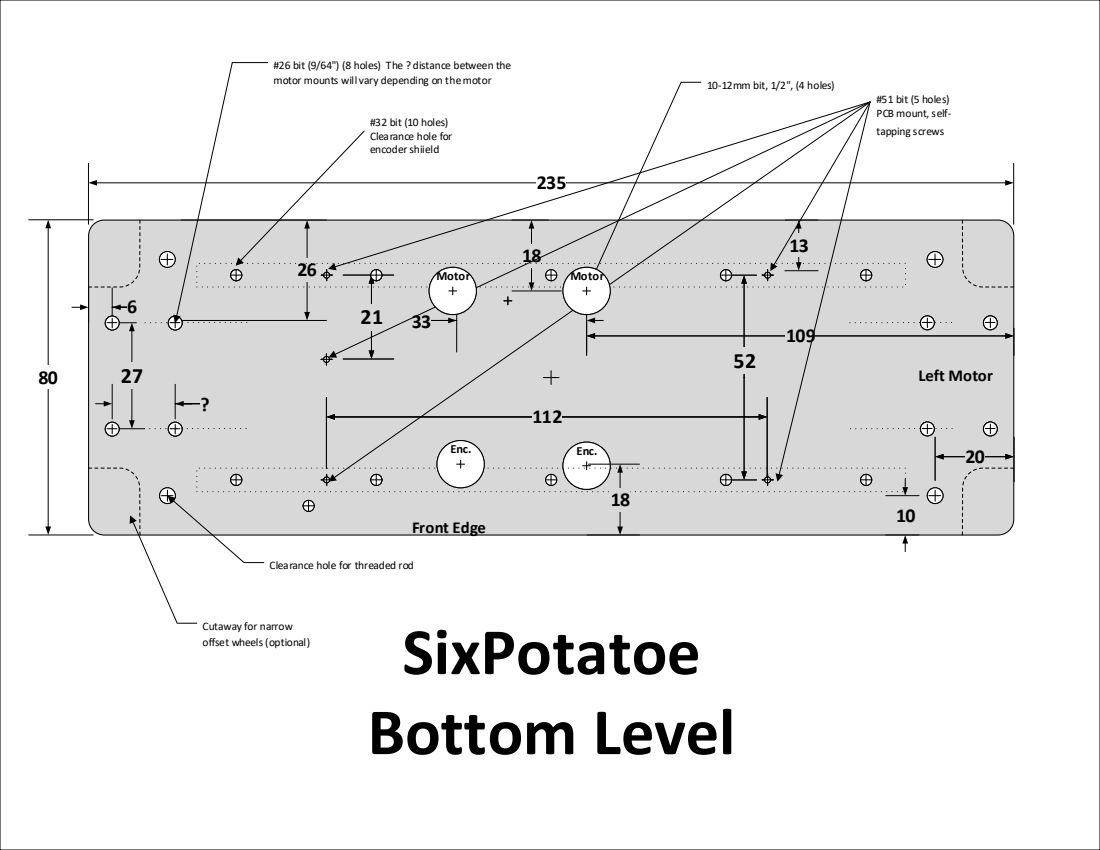
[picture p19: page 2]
SixPotatoe Bottom Level; Front Edge; 10-12mm bit, 1/2", (4 holes); Left Motor; Motor; Enc.

#26 bit (9/64") (8 holes) The ? distance between the
motor mounts will vary depending on the motor

#51 bit (5 holes)
PCB mount, self-
tapping screws

#32 bit (10 holes)
Clearance hole for
encoder shiield

Clearance hole for threaded rod

Cutaway for narrow
offset wheels (optional)

## Bumper #2

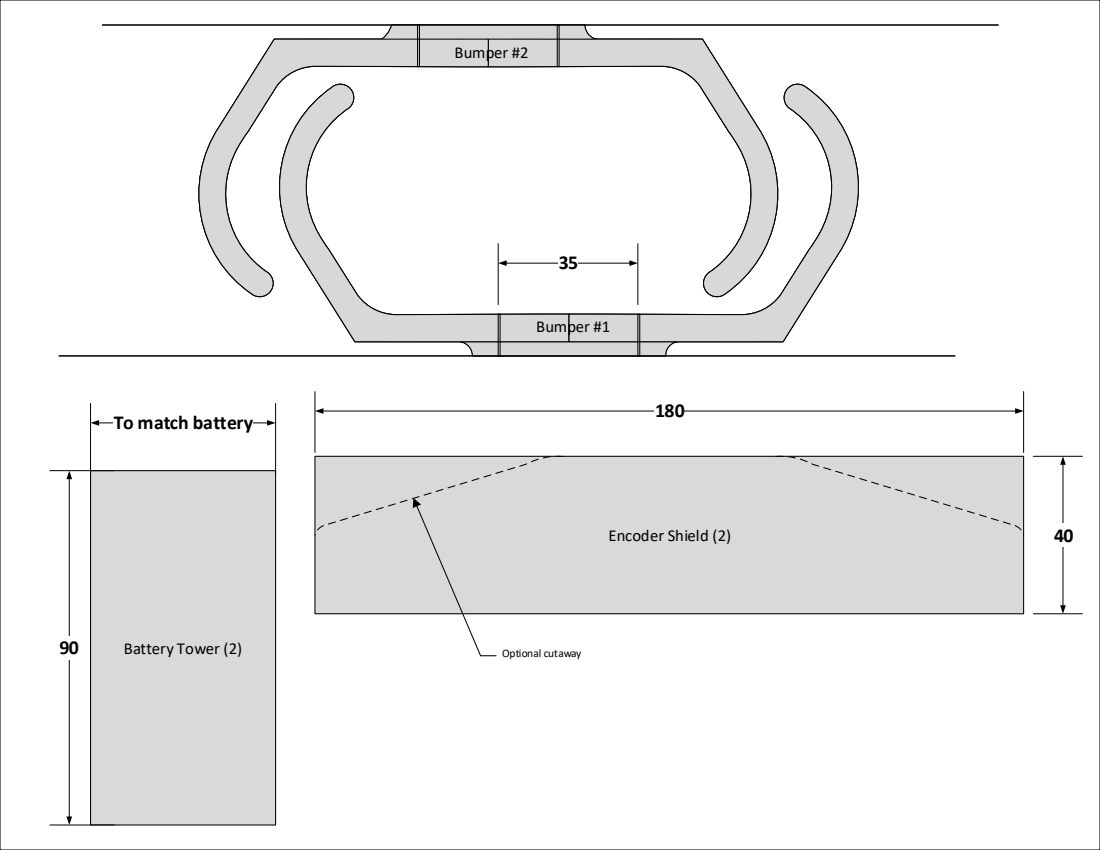
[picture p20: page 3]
Bumper #1; Battery Tower (2); Encoder Shield (2); To match battery; Optional cutaway

Right Motor | Left Motor

## Encoder

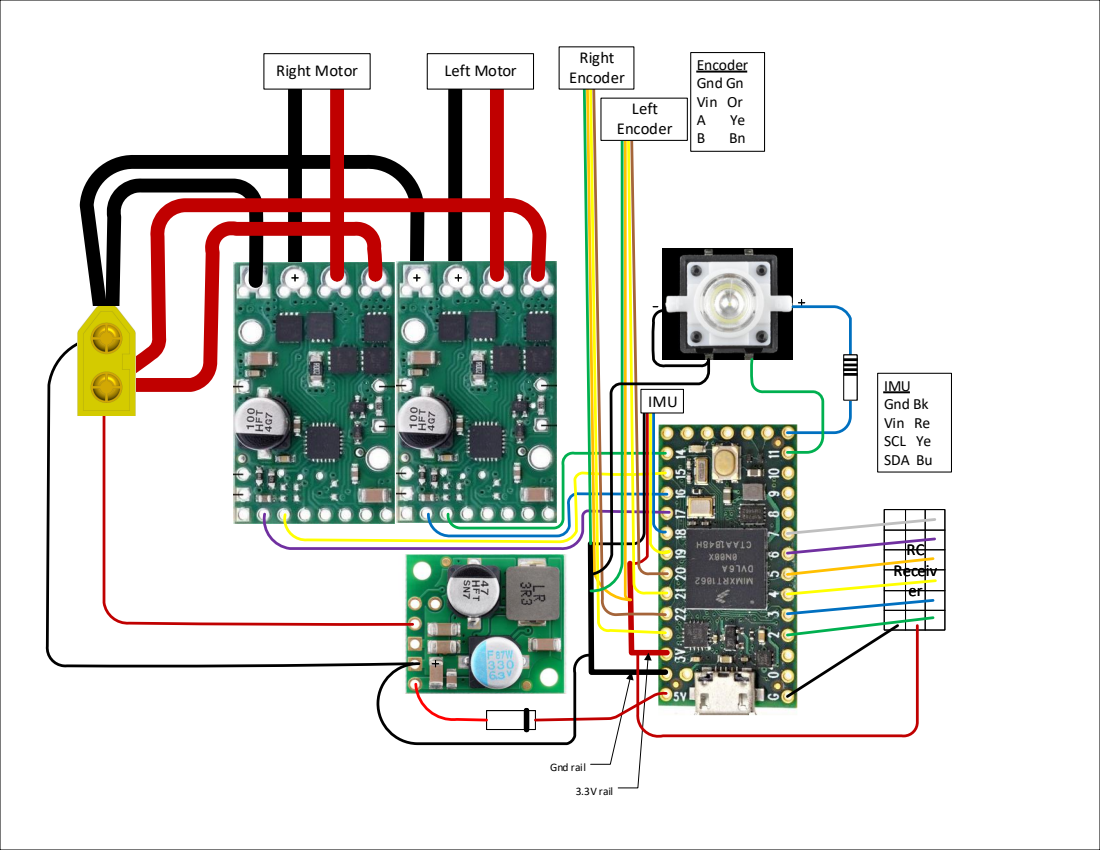
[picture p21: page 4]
3.3V rail; Gnd rail; IMU; Gnd Gn Vin Or; Left Encoder; Right Encoder; RC Receiv er; IMU Gnd Bk Vin Re SCL Ye SDA Bu

Throttle
Gain

Steer
Gain

Steer
Zero

Throttle
Zero

1

2

54

3

## Route

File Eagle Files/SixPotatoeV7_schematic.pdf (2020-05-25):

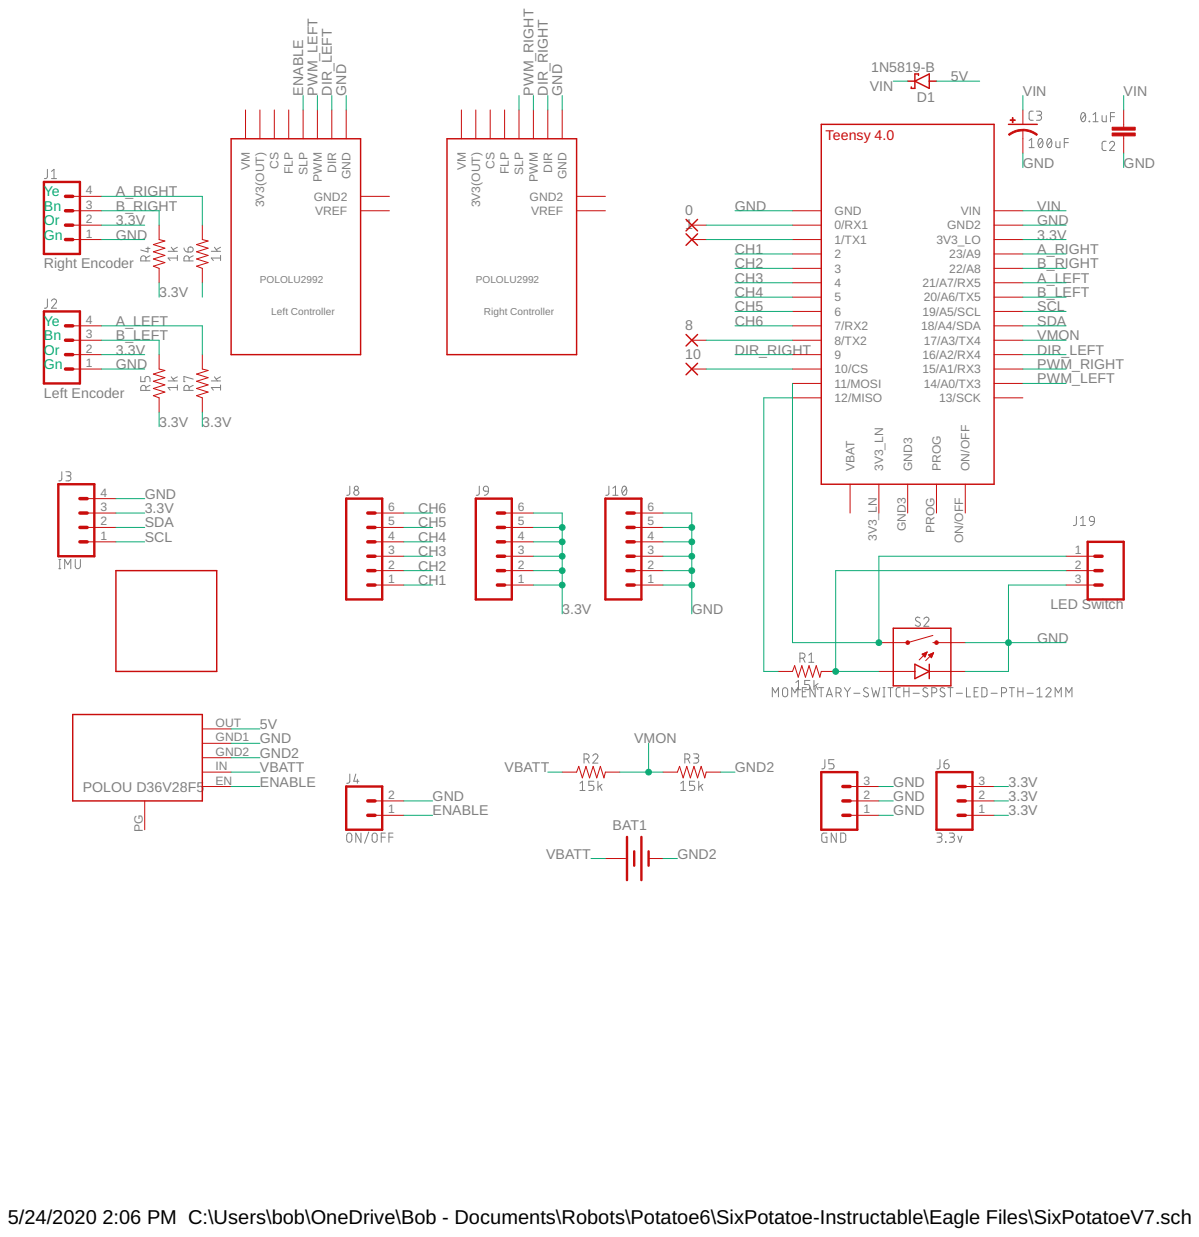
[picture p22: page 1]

ON/OFF

5/24/2020 2:06 PM C:\Users\bob\OneDrive\Bob - Documents\Robots\Potatoe6\SixPotatoe-Instructable\Eagle Files\SixPotatoeV7.sch (Sheet: 1/1)

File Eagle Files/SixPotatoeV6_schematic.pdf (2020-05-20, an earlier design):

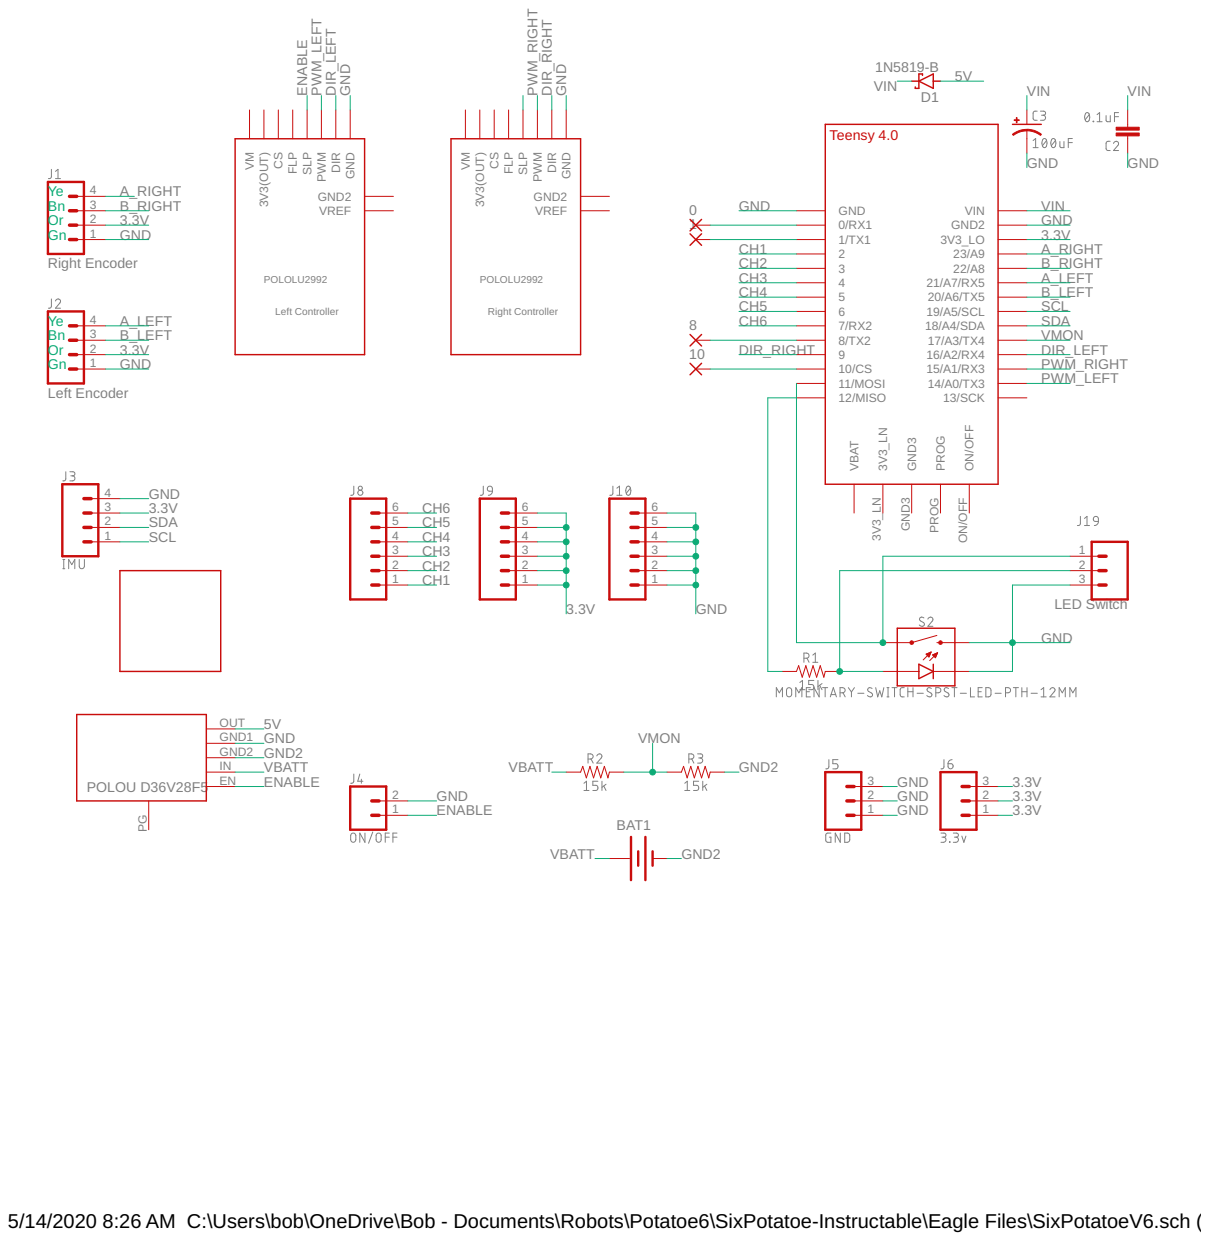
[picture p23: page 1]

ON/OFF

5/14/2020 8:26 AM C:\Users\bob\OneDrive\Bob - Documents\Robots\Potatoe6\SixPotatoe-Instructable\Eagle Files\SixPotatoeV6.sch (Sheet: 1/1)

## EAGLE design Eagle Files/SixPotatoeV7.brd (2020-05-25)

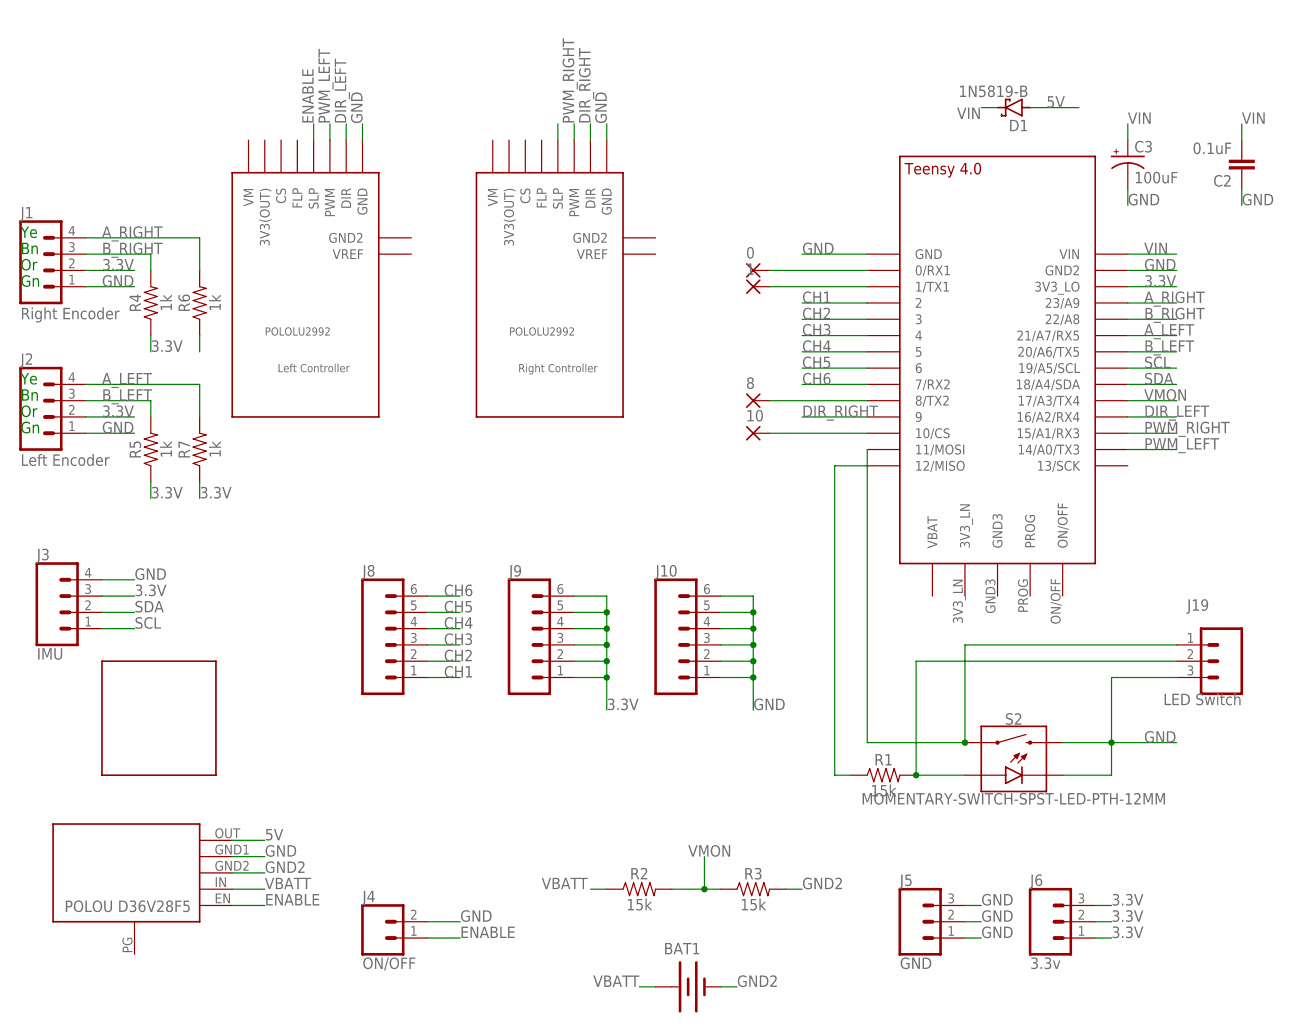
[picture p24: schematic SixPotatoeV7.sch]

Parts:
0, 1, 8, 10: 2,15/1,0
BAT1: XT60_MALE; XT60
C2: 0.1uF; CAP-PTH-SMALL-KIT
C3: 100uF; CPOL-RADIAL-2.5MM-6.5MM
D1: 1N5819-B; DO41-7.6
J1, J2: CONN_04; 1X04
J3: IMU; 1X04
J4: ON/OFF; 1X02
J5: GND; 1X03
J6: 3.3v; 1X03
J8, J9, J10: CONN_06NO_SILK_FEMALE_PTH; 1X06_NO_SILK
J19: CONN_03; 1X03
R1, R2, R3: 15k; AXIAL-0.3
R4, R5, R6, R7: 1k; AXIAL-0.3
S2: MOMENTARY-SWITCH-SPST-LED-PTH-12MM; TACTILE_SWITCH_LED_PTH_12MM
U$1: TEENSY_4.0
U$2: Left Controller; POLOLU2992_2
U$3: Right Controller; POLOLU2992_2
U$4: POLOU3782
U$5: SEN15335_NO_PTH

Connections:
3.3V: J1.2, J2.2, J3.3, J6.1, J6.2, J6.3, J9.1, J9.2, J9.3, J9.4, J9.5, J9.6, R4.P$1 (1), R5.P$1 (1), R6.P$1 (1), R7.P$1 (1), U$1.3V3_LO
5V: D1.A, U$4.OUT
A_LEFT: J2.4, R7.P$2 (2), U$1.21/A7 (21/A7/RX5)
A_RIGHT: J1.4, R6.P$2 (2), U$1.23/A9
B_LEFT: J2.3, R5.P$2 (2), U$1.20/A6 (20/A6/TX5)
B_RIGHT: J1.3, R4.P$2 (2), U$1.22/A8
CH1: J8.1, U$1.2
CH2: J8.2, U$1.3/CANTX (3)
CH3: J8.3, U$1.4/CANRX (4)
CH4: J8.4, U$1.5
CH5: J8.5, U$1.6
CH6: J8.6, U$1.7 (7/RX2)
DIR_LEFT: U$1.16/A2 (16/A2/RX4), U$2.DIR
DIR_RIGHT: U$1.9/CS (9), U$3.DIR
ENABLE: J4.1, U$2.SLP, U$3.SLP, U$4.EN
GND: C2.1, C3.2 (-), J1.1, J2.1, J3.4, J4.2, J5.1, J5.2, J5.3, J10.1, J10.2, J10.3, J10.4, J10.5, J10.6, J19.3, S2.2, S2.C, U$1.GND, U$1.GND2, U$2.GND, U$3.GND, U$4.GND1
GND2: BAT1.-, R3.P$2 (2), U$4.GND2
unnamed: 0.1, U$1.0/RX (0/RX1)
unnamed: J19.2, R1.P$2 (2), S2.A
unnamed: R1.P$1 (1), U$1.12/MISO
unnamed: J19.1, S2.4 (1), U$1.11/MOSI
unnamed: 1.1, U$1.1/TX (1/TX1)
unnamed: 10.1, U$1.10/CS
unnamed: 8.1, U$1.8 (8/TX2)
PWM_LEFT: U$1.14/A0 (14/A0/TX3), U$2.PWM
PWM_RIGHT: U$1.15/A1 (15/A1/RX3), U$3.PWM
SCL: J3.1, U$1.19/A5/SCL
SDA: J3.2, U$1.18/A4/SDA
VBATT: BAT1.+, R2.P$1 (1), U$4.IN
VIN: C2.2, C3.1 (+), D1.C, U$1.VIN
VMON: R2.P$2 (2), R3.P$1 (1), U$1.17/A3 (17/A3/TX4)

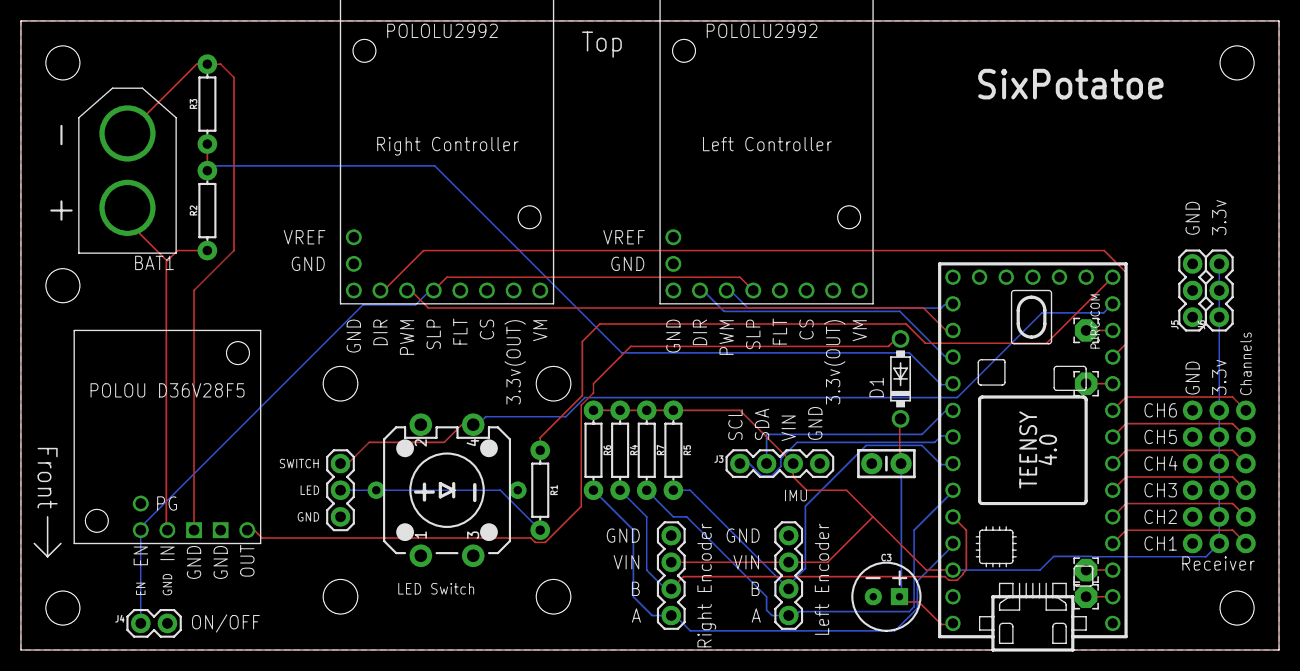
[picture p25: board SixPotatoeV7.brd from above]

Board: 2 copper layers, 120.0 x 60.0 mm, 31 parts (1 on the bottom side), 31 nets.

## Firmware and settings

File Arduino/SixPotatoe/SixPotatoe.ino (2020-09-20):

/*****************************************************************************-
 *                            SixPotatoe.ino
 *****************************************************************************/
#include <Wire.h>
#include "IMU.h"
#include "Routes.h"
#include "Defs.h"

#ifdef YELLOW_435
const float MOTOR_RPM = 435.0;        // RPM at 12V
const float MOTOR_GEAR_RATIO = 13.7;
const float MOTOR_EVENTS = 28.0;       // Encoder ticks per motor revolution
const bool ENCODER_PHASE = false;
const float K0_MULT = 0.42;
const float K5_MULT = 1.5;
const float K13_MULT = 1.0;
const float K14_MULT = 1.0;
#endif // YELLOW_435

#ifdef HD_437
const float MOTOR_RPM = 437.0;          // RPM at 12V
const float MOTOR_GEAR_RATIO = 19.2;
const float MOTOR_EVENTS = 48.0;        // Encoder ticks per motor revolution
const bool ENCODER_PHASE = false;
const float K0_MULT = 0.42;
const float K5_MULT = 1.5;
const float K13_MULT = 1.0;
const float K14_MULT = 1.0;
#endif // HD_437

#ifdef HD_612
const float MOTOR_RPM = 612.0;          // RPM at 12V
const float MOTOR_GEAR_RATIO = 13.7;
const float MOTOR_EVENTS = 48.0;        // Encoder ticks per motor revolution
const bool ENCODER_PHASE = false;
const float K0_MULT = 0.42;            // Motor gain
const float K5_MULT = 1.5;             // Speed error to angle
const float K13_MULT = 1.0;            // Constrain pitch error
const float K14_MULT = 1.0;            // Angle error gain
#endif // HD_612

#ifdef YELLOW_1150
const float MOTOR_RPM = 1150.0;         // RPM at 12V
const float MOTOR_GEAR_RATIO = 5.2;
const float MOTOR_EVENTS = 28.0;        // Encoder ticks per motor revolution
const bool ENCODER_PHASE = false;
const float K0_MULT = 0.9;              // Motor gain
const float K5_MULT = 0.8;              // Speed error to angle
const float K13_MULT = 1.0;             // Constrain pitch error
const float K14_MULT = 1.0;             // Angle error gain
#endif // YELLOW_1150

const float BATT_ADJUST = BATTERY_VOLTS / 25.2;
const float MAX_MOTOR_RPM = (BATTERY_VOLTS / NOMINAL_VOLTS) * MOTOR_RPM;
const float TICKS_PER_ROTATION = MOTOR_EVENTS * MOTOR_GEAR_RATIO;
const float MAX_MOTOR_KPH =  (WHEEL_DIA_MM * M_PI * MAX_MOTOR_RPM * 60.0) / 1000000.0;
const float USEC_TO_KPH = (3600.0 * WHEEL_DIA_MM * M_PI) / TICKS_PER_ROTATION;
const float KPH_TO_PW = 255.0 / MAX_MOTOR_KPH;
const float TICKS_PER_METER = (1000.0 / (M_PI * WHEEL_DIA_MM)) * TICKS_PER_ROTATION;

/*****************************************************************************-
 *  Pin definitions
 *****************************************************************************/
const int PWM_LEFT_PIN    = 14;
const int PWM_RIGHT_PIN   = 15;
const int DIR_LEFT_PIN    = 16;
const int DIR_RIGHT_PIN   =  9;

const int ENC_B_LEFT_PIN  = 20;
const int ENC_A_LEFT_PIN  = 21;
const int ENC_B_RIGHT_PIN = 22;
const int ENC_A_RIGHT_PIN = 23;

const int CH1_RADIO_PIN   =  7;
const int CH2_RADIO_PIN   =  6;
const int CH3_RADIO_PIN   =  5;
const int CH4_RADIO_PIN   =  4;
const int CH5_RADIO_PIN   =  3;
const int CH6_RADIO_PIN   =  2;

const int LED_PIN         = 13;
const int LED_STAT_PIN    = 12;
const int SW_STAT_PIN     = 11;
const int BATTERY_PIN     = 17;

enum BlinkState {
  BLINK_OFF,        //  motors off, no route
  BLINK_ON,         //  motors on,  no route 
  BLINK_SLOW_FLASH, //  motors off, running route
  BLINK_SLOW,       //  motors on,  running route
  BLINK_FAST_FLASH  //  motors on,  fallen
};

BlinkState currentBlink = BLINK_OFF;

// Data logging
String logHeader = "No Header";  // Set this if you want to add labels.
#define N_8FLOAT_LOGS 10000      // ~10,000 max. Set to 1 when not logging. 
#define N_4FLOAT_LOGS 1      // ~20,000 max. Set to 1 when not logging. 
#define N_TICK_LOGS   1      // ~40,000 max. Set to 1 when not logging.
float log8Floats[8][N_8FLOAT_LOGS];
int log8FloatCount = 0;
boolean isLog8FloatWrap = false;
float log4Floats[4][N_4FLOAT_LOGS];
int log4FloatCount = 0;
boolean isLog4FloatWrap = false;

// Tick logging
unsigned long tickLogRight[N_TICK_LOGS];
unsigned long tickLogLeft[N_TICK_LOGS];
byte intLogRight[N_TICK_LOGS];
byte intLogLeft[N_TICK_LOGS];
int tcRight = 0;
int tcLeft = 0;

// Motor varialbles
const float K0_RESULT = K0 * K0_MULT; // adjust gain by motor torque
const float K5_RESULT = K5 * K5_MULT;
const float K14_RESULT = K14 * K14_MULT;  // Error gain.
const float K13_RESULT = K13 * K13_MULT;

// Motor state bits
const byte STATE_DIR = B00001000;
const byte STATE_ISA = B00000100;
const byte STATE_A =   B00000010;
const byte STATE_B =   B00000001;

const int N_TICK_BUFF = 200;
volatile unsigned long tickTimesRight[N_TICK_BUFF];
volatile unsigned long tickTimesLeft[N_TICK_BUFF];
volatile byte tickStatesRight[N_TICK_BUFF];
volatile byte tickStatesLeft[N_TICK_BUFF];
volatile int tickPtrRight = 0;
volatile int tickPtrLeft = 0;
volatile int interruptErrorsRightA = 0;
volatile int interruptErrorsLeftA = 0;
volatile int interruptErrorsRightB = 0;
volatile int interruptErrorsLeftB = 0;
volatile int interruptErrorsRightC = 0;
volatile int interruptErrorsLeftC = 0;
volatile int ticksRight = 0;
volatile int ticksLeft = 0;

float wKphRight = 0.0;
float wKphLeft = 0.0;
float wKph = 0.0;
float targetWKphRight = 0.0;
float motorTargetKphRight = 0.0;
float targetWKphLeft = 0.0;
float motorTargetKphLeft = 0.0;
int motorPwRight = 0;
int motorPwLeft = 0;

// Run variables
float coKph = 0.0;
float balanceTargetKph = 0.0;
float balanceSteerAdjustment = 0.0;
float targetWKph = 0.0;
unsigned long timeMilliseconds = 0UL;
unsigned long timeMicroseconds = 0UL;
bool isRunning = false;
bool isBowlBalancing = false;
bool isAir = false;
bool isUpright = false;
bool isZeroG = false;
bool isBatteryWarn = false;
bool isBatteryCritical = false;
float zeroGKph = 0.0;
int tickPositionRight = 0;
int tickPositionLeft = 0;
int tickPosition = 0L;
double tickMeters = 0.0;
double coTickPosition = 0.0;

// RC variables
volatile float controllerX = 0.0;   // ch1 steering
volatile float controllerY = 0.0;   // ch2 throttle/accelerator
volatile int ch3Pw = 0;
volatile boolean ch3State = false;  // ch3 toggle
volatile int ch4Pw = 0; 
volatile int ch4State = 0;          // ch4 3-position switch
volatile float ch5Val = 0.0;        // ch5 top left potentiometer
volatile int ch5Pw = 0;
volatile int ch5State = 0;          // ch5 states 1-5
volatile float ch6Val = 0.0;        // ch6 top right potentiometer.

// Nav public variables
struct loc {
  double x;
  double y;
};
struct loc currentLoc;
struct loc targetLoc;
struct loc pivotLoc;
//struct loc hugStartLoc;
struct loc coSetLoc;
unsigned long timeRun = 0;
char routeCurrentAction = 0;
int routeStepPtr = 0;
boolean isStartReceived = false;
boolean isRouteInProgress = false;
float routeKph = 0.0;
float turnRadius = 0.0;
String *currentRoute = routeTable[0];
const float STEP_ERROR = -42.42;
int originalStepStringPtr = 0;
String stepString = "";
int numLen = 0;
double dDiff = 0.0D;
float targetBearing = 0.0;
float targetDistance = 0.0;
float targetRunDistance = 0.0;
float startTurnBearing = 0.0;
float currentRotation = 0.0;
float stepRotation = 0.0;
double stepDistance = 0.0D;
double currentDistance = 0.0D;
double startOrientation = 0.0;
struct loc startLoc;
enum {
  PHASE1,
  PHASE2,
  PHASE3
} getUpPhase = PHASE1;
unsigned long getUpStartTime = 0;
const int GU_PHASE_1 = 0;
bool isGetUpPhase1 = true;
bool isGetUpBack = false;
unsigned long getUpPhase1Ms = 400;
unsigned long getUpPhase2Ms = 200;
float getUpPhase1Kph = 6.0;
float getUpPhase2Kph = 12.0;
  
IMU imu;



/*****************************************************************************_
 * setup()
 *****************************************************************************/
void setup() {
  Serial.begin(115200);
  Wire.begin();
//  Wire.setClock(400000);
 
  // Motor pins are initialized in motorInit()
  pinMode(LED_PIN, OUTPUT);
  pinMode(LED_STAT_PIN, OUTPUT);
  pinMode(SW_STAT_PIN, INPUT_PULLUP);
  pinMode(BATTERY_PIN, INPUT);
    
  digitalWrite(LED_PIN, HIGH);
  digitalWrite(LED_STAT_PIN, LOW);

  rcInit(); 
  imu.imuInit(Wire, 1);
  motorInit();
  delay(100); // For switches?
}



/*******************************************************************************
 * loop()
 ******************************************************************************/
void loop() {
  if (IS_TEST1) systemTest1();
  else if (IS_TEST2)  systemTest2();
  else if (IS_TEST3)  systemTest3();
  else if (IS_TEST4)  systemTest4();
  else run();
}



/*****************************************************************************-
 * systemTest?()  
 *           TODO Explain test
 *****************************************************************************/

void systemTest1() {  // Check IMU
  static unsigned long lastT = 0;
  if (imu.isNewImuData()) {
    unsigned long newT = micros();
    Serial.printf("Pitch:%6.2f   Roll:%6.2f   Yaw:%6.2f   Period:%2d usec\n", 
                  imu.maPitch, imu.maRoll, imu.maYaw, ((int) (newT - lastT)));
    lastT = newT;
    blinkTeensy();
  }
}

void systemTest2() {  // Check the RC controller
  static boolean toggle = false;
  static int m = 0;
  if (imu.isNewImuData()) {
    if ((m++ % 10) == 0) { 
      digitalWrite(LED_PIN, (toggle = !toggle) ? HIGH : LOW);
//      Serial.printf("ch1:%5.2f     ch2:%5.2f     ch3:%1d     ch4:%1d     ch5:%5.2f   ch5St5ate:%1d    ch6:%5.2f\n", 
//                    controllerX, controllerY, ch3State, ch4State, ch5Val, ch5State, ch6Val);
      Serial.printf("ch1:%5.2f     ch2:%5.2f     ch3:%1d     ch4:%1d     ch5:%2d   ch3Pw:%4d  ch4pw:%4d  ch5Pw:%4d\n", 
                    controllerX, controllerY, ch3State, ch4State, ch5State, ch3Pw, ch4Pw, ch5Pw);
    }
    blinkTeensy();
  }
}

void systemTest3() {  // Check motor controlers and encoders
  while (true) {
    commonTasks();
    if (imu.isNewImuData()) {
      int x = (int) (controllerX * 20.0);
      int y = (int) (controllerY * 255.0);
      int r = y + x;
      int l = y - x;
      setMotorRight(r);
      setMotorLeft(l);
      readSpeedRight();
      readSpeedLeft();
      Serial.printf("%7.2f %7.2f %5d %5d %5d\n", wKphRight, wKphLeft, r, l, isRunning);
      blinkTeensy();
    }
  }
}

void systemTest4() {  // Check speed control
  while (true) {
    commonTasks();
    if (imu.isNewImuData()) {
      float x = (controllerX * 5.0);
      float y = (controllerY * 10.0);
      targetWKphRight = y + x;
      targetWKphLeft = y - x;
      runMotors();
      Serial.printf("%7.2f %7.2f %7.2f %7.2f %5d\n", wKphRight, wKphLeft, x, y, isRunning);
      blinkTeensy();
    }
  }
}

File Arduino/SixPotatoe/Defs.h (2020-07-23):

/*****************************************************************************-
 *                            Defs.h
 *    Normally, this will be the only file that the user needs to modify.
 *    This is where the motor and battery are specified.  There are also
 *    a number of "K" constants that can be adjusted to tune various aspects
 *    of SixPotatoe's performance.  
 *****************************************************************************/
#ifndef _DEFS_H_
#define _DEFS_H_

// The motor is defined here.  Uncomment the line for the motor you are using.
//#define YELLOW_435   
//#define YELLOW_1150   
//#define HD_437
//#define HD_612

const float WHEEL_DIA_MM = 120.6;  // The diameter of the wheel.
const float NOMINAL_VOLTS = 12.0;  // Voltage at which motor is rated.
const float BATTERY_VOLTS = 25.2;  // 6 cells at 4.2V per cell


// Tunable constants
const float K0  = 10.0;     // Motor gain.  
const float K1  = 1.6;      // Pitch delta to COS
const float K2  = 0.05;     // 1.0 passes all hf, near zero passes only low freq.
const float K3  = 0.213;    // Accelerometer to Kph
const float K4  = 0.2;      // targetKph rate of change limit per cycle
const float K5  = 2.0;      // Angle Gain. Speed error to angle
const float K6  = 0.2;      // TC for predicted kph
const float K8  = 0.2;      // bowl roll compensation at top.
const float K10 = 1.4;      // accelerometer pitch offset
const float K12 = 50.0;     // +- constraint on target pitch
const float K13 = 30.0;     // +- constraint on pitch error to prevent too rapid righting
const float K14 = 0.15;     // Angle error to Kph
const float K15 = 70;       // pitch beyond which is considered to not be upright
const int   K16 = 50;       // ms time for pitch < K16 to be not upright
const float K17 = 0.1;      // "D"
const int   K20 = 150;      // LED brightness, 0-255;
const float K21 = 0.95;     // TC for accelCoKph
const float K30 = 0.7;      // proportion of MAX_MOTOR_KPH for max kph
const float K31 = 5.0;      // Maximum speed for Kph on ground.
const float K32 = 2.0;      // Maximum steering on ground.
const float K40 = 1.000;    // gyro correction


// One of the following are set to "true" for initial testing.
const bool IS_TEST1 = false;  // Set to be true for the 1st system test.
const bool IS_TEST2 = false;  // Set to be true for the 2nd system test.
const bool IS_TEST3 = false;  // Set to be true for the 3nd system test.
const bool IS_TEST4 = false;  // Set to be true for the 4th system test.

#endif  // _DEFS_H_

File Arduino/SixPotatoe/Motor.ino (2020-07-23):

/*****************************************************************************-
 *                        Motor.ino
 *****************************************************************************/
volatile unsigned long timesLeft[5];
volatile bool dirsLeft[5];
volatile int ptrLeft = 0;
volatile int tickCountLeft = 0;
volatile unsigned long timesRight[5];
volatile bool dirsRight[5];
volatile int ptrRight = 0;
volatile int tickCountRight = 0;

/*****************************************************************************-
 *  motorInit()
 *****************************************************************************/
void motorInit() {
  pinMode(DIR_RIGHT_PIN, OUTPUT);
  pinMode(DIR_LEFT_PIN, OUTPUT);
  pinMode(ENC_A_RIGHT_PIN, INPUT);
  pinMode(ENC_A_LEFT_PIN, INPUT);
  pinMode(ENC_B_RIGHT_PIN, INPUT);
  pinMode(ENC_B_LEFT_PIN, INPUT);

  analogWriteFrequency(PWM_RIGHT_PIN, 20000);
  analogWriteFrequency(PWM_LEFT_PIN, 20000);

  digitalWrite(DIR_RIGHT_PIN, LOW);
  digitalWrite(DIR_LEFT_PIN, LOW);
  analogWrite(PWM_RIGHT_PIN, 0);
  analogWrite(PWM_LEFT_PIN, 0);

  attachInterrupt(digitalPinToInterrupt(ENC_A_RIGHT_PIN), encoderIsrRightA, CHANGE);
  attachInterrupt(digitalPinToInterrupt(ENC_B_RIGHT_PIN), encoderIsrRightB, CHANGE);
  attachInterrupt(digitalPinToInterrupt(ENC_A_LEFT_PIN), encoderIsrLeftA, CHANGE);
  attachInterrupt(digitalPinToInterrupt(ENC_B_LEFT_PIN), encoderIsrLeftB, CHANGE);
}



/*****************************************************************************-
 * encoderIsr???()
 *****************************************************************************/
void encoderIsrRightA() { encoderIsrRight(true); }
void encoderIsrRightB() { encoderIsrRight(false); }
void encoderIsrRight(bool isA) {
  static bool oldA = true;
  static bool oldB = true;
  static bool isLastA = true;
  static unsigned int lastTickTime = 0ul;
 
  boolean encA = (digitalReadFast(ENC_A_RIGHT_PIN) == HIGH) ? true : false;
  boolean encB = (digitalReadFast(ENC_B_RIGHT_PIN) == HIGH) ? true : false;
  unsigned long tickTime = micros();
  bool isFlipA = (encA != oldA);
  bool isFlipB = (encB != oldB);
  oldA = encA;
  oldB = encB;
//  addTickLog(tickTimeRight, isMotFwd, isA, encA, encB);
  if ((isA && !isFlipA) || (!isA && !isFlipB)) {
    interruptErrorsRightA++; // Bogus unterrupt'
    return;
  }
  if (isLastA == isA) {
    interruptErrorsRightB++;  // Bogus unterrupt or direction change.
    return;
  }
  if ((tickTime - lastTickTime) < 55) {
    interruptErrorsRightC++;  // Shouldn't happen
  }
  isLastA = isA;
  lastTickTime = tickTime;

  bool isFwd;
  if      (isA  && (encA == encB)) isFwd = true;
  else if (!isA && (encA != encB)) isFwd = true;
  else                             isFwd = false;
  byte stateByte = (isFwd) ? STATE_DIR : 0;
  stateByte     |= (isA)   ? STATE_ISA : 0;
  stateByte     |= (encA)  ? STATE_A : 0;
  stateByte     |= (encB)  ? STATE_B : 0;
  
  tickPtrRight++;
  tickPtrRight %= N_TICK_BUFF;
  tickTimesRight[tickPtrRight] = tickTime;
  tickStatesRight[tickPtrRight] = stateByte;
  ticksRight++;
} // encoderIsrRight()


/*****************************************************************************-
   encoderIsrLeft()
 *****************************************************************************/
void encoderIsrLeftA() { encoderIsrLeft(true); }
void encoderIsrLeftB() { encoderIsrLeft(false); }
void encoderIsrLeft(bool isA) {
  static bool oldA = true;
  static bool oldB = true;
  static bool isLastA = true;
  static unsigned int lastTickTime = 0ul;
 
  boolean encA = (digitalReadFast(ENC_A_LEFT_PIN) == HIGH) ? true : false;
  boolean encB = (digitalReadFast(ENC_B_LEFT_PIN) == HIGH) ? true : false;
  unsigned long tickTime = micros();
  bool isFlipA = encA == oldA;
  bool isFlipB = encB == oldB;
  oldA = encA;
  oldB = encB;
  
  if ((isA && isFlipA) || (!isA &&isFlipB)) {
    interruptErrorsLeftA++; // Bogus unterrupt'
    return;
  }
  if (isLastA == isA) {
    interruptErrorsLeftB++;  // Bogus unterrupt or direction change.
    return;
  }
  if ((tickTime - lastTickTime) < 55) {
    interruptErrorsLeftC++;  // Shouldn't happen
  }
  isLastA = isA;
  lastTickTime = tickTime;

  bool isFwd;
  if      (isA  && (encA == encB)) isFwd = false;
  else if (!isA && (encA != encB)) isFwd = false;
  else                             isFwd = true;
  byte stateByte = (isFwd) ? STATE_DIR : 0;
  stateByte     |= (isA)   ? STATE_ISA : 0;
  stateByte     |= (encA)  ? STATE_A : 0;
  stateByte     |= (encB)  ? STATE_B : 0;
  
  tickPtrLeft++;
  tickPtrLeft %= N_TICK_BUFF;
  tickTimesLeft[tickPtrLeft] = tickTime;
  tickStatesLeft[tickPtrLeft] = stateByte;
  ticksLeft++;
} // end encoderIsrLeft();



/*****************************************************************************-
 * readSpeed????()  Called every loop from CheckMotor()
 *****************************************************************************/
void readSpeedRight() {
  static float predictedKphRight = 0.0;
  static int oldTickPtr = 0;
  
  int tickSum = 0;
  int tickCount = 0;
  bool isEndFwd = false;

  // Calculate predicted kph
  float tgtKph =((float) motorPwRight) / KPH_TO_PW;
  float pdiff = predictedKphRight - tgtKph;
  predictedKphRight -= pdiff * K6;

  bool isStartFwd = ((tickStatesRight[oldTickPtr] & STATE_DIR) != 0) ^ ENCODER_PHASE;
  tickCount = ((tickPtrRight + N_TICK_BUFF) - oldTickPtr) % N_TICK_BUFF;
  if (tickCount == 0) { // No interrupts?
    unsigned long t = micros();
    int period = t - tickTimesRight[tickPtrRight];
    float newKph = USEC_TO_KPH / ((float) period);
    if (abs(newKph) < abs(wKphRight)) {
      wKphRight = newKph;
      if (!isStartFwd) wKphRight *= -1.0;
    }
  } else {
    if ((MOTOR_EVENTS < 30) && (tickCount < 3)) {
      oldTickPtr = tickPtrRight - 4;
      if (oldTickPtr < 0) oldTickPtr += N_TICK_BUFF;
      tickCount = 4;
    }
    for (int i = 0; i < tickCount; i++) {
      tickSum += tickTimesRight[(oldTickPtr + 1) % N_TICK_BUFF] - tickTimesRight[oldTickPtr];
      oldTickPtr++;
      oldTickPtr %= N_TICK_BUFF;
      isEndFwd = ((tickStatesRight[oldTickPtr] & STATE_DIR) != 0) ^ ENCODER_PHASE;
      tickPositionRight +=  (isEndFwd) ? 1 : -1;
    }
    int period = tickSum / tickCount;
    wKphRight = USEC_TO_KPH / ((float) period);
    if (isStartFwd != isEndFwd) wKphRight = 0.0;
    if (!isEndFwd) wKphRight *= -1.0;
  }
if (abs(wKphRight) > 0.1) Serial.printf("%6.2f  %6.2f %6.2f\n", wKphRight, predictedKphRight, pdiff);
if (isRunning) add8Log(wKphRight, predictedKphRight, imu.maPitch, motorPwRight, 
                       (float) interruptErrorsRightA,
                       (float) interruptErrorsRightB,
                       (float) interruptErrorsRightC,
                       0.0);

}
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

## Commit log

2020-05-11 Initial commit of the Arduino code
2020-05-11 Add Eagle files
    [SixPotatoeV6.brd, SixPotatoeV6.sch]
2020-05-20 Video completed
    Also, excess code removed, first routes checked out.
    [SixPotatoeV4.brd, SixPotatoeV4.sch, SixPotatoeV5.brd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]
2020-05-25 Updated for V7 boards
    [SixPotatoeV7.brd, SixPotatoeV7.sch]
2020-06-03 New PCB pin defs
    Also battery monitoring
2020-06-04 Version 7 Gerber files for PCB
2020-06-07 Checkin before encoder equalizing added
2020-06-26 Add encoder equalization
    Encoder now used last 4 ticks for kph. This checkin is before changeds to be made for 612 RPM motor.
2020-06-26 612 RPM motor working
2020-07-08 Before isr mods
    This is a check-in before the new isr mods are added. The actual interrupt times are put in a buffer and read out by the readSpeed?() routines.
2020-07-11 Release 10-Jun-2020
    Many fixes, mods & enhancements.
    [Defs.h, IMU.cpp, IMU.h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]
2020-07-11 Revert "Release 10-Jun-2020"
    This reverts commit 6ae50b53aa5354b7f7f80889ba46ecac2c478f51.
    [Defs.h, IMU.cpp, IMU.h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]
2020-07-23 New faster IMU reads
2020-08-05 Low speed steering
2020-09-20 Battery events
    Fixed the battery() routine so that it adjusts properly for different battery voltages.
    [SixPotatoe.ino, Tasks.ino]

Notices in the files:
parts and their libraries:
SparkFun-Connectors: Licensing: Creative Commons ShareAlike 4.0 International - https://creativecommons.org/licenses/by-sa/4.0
